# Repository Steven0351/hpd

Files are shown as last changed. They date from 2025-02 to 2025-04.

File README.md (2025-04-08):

## High Plains Drifter is a modular, curved mechanical keyboard that is ready to change the way you think about ergonomics in typing!  
*Innovative design that allows easy access to all keys, and specially designed modules that make the keyboard a unique tool, exclusively for your purpose*

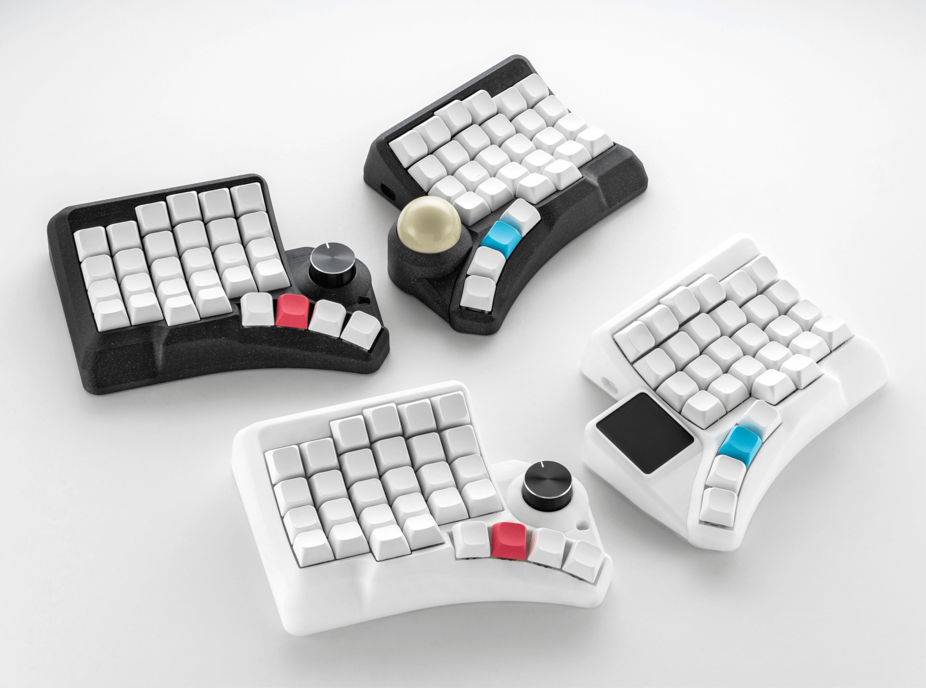
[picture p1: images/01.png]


## Design philosphy
This keyboard was designed with FDM printing in mind, the goal was to create a perfect curved case that can be easily printed and looks aesthetically pleasing with minimal amount of so called "steps" that plague similar 3D keyboards like Dactyl Manuform, it's design is similar to the [Velvet v3](https://github.com/ergohaven/velvet) keyboard but with 60% layout and addition of various interchangeable modules
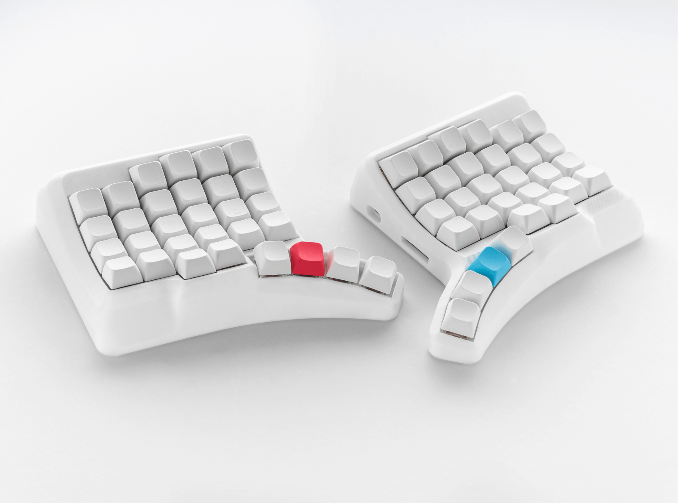
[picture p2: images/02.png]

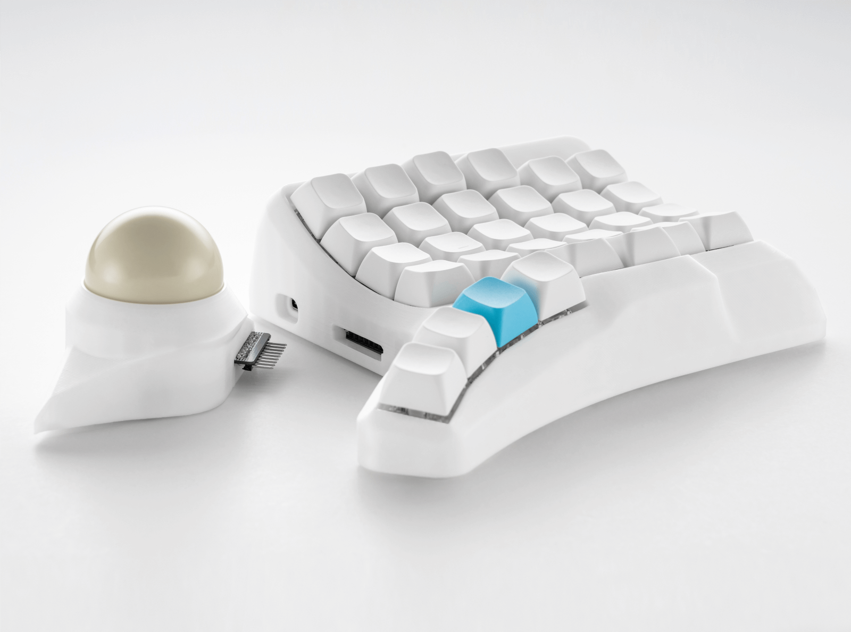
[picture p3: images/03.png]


## Features
- Modular, ergonomic 3D design
- 60 fully programmable keys, 15 additional layers for all your tasks
- Powered by RP2040 Zero and QMK firmware
- Hotswappable PCB (MX sockets) 
- Type-C output for connection between halves
- Easily remap any key and customize your keyboard with [Vial](https://get.vial.today/) 
- [Firmware](https://github.com/ergohaven/keymap_hub) is being constantly updated, get the latest QMK features for your keyboard from us ♥️  

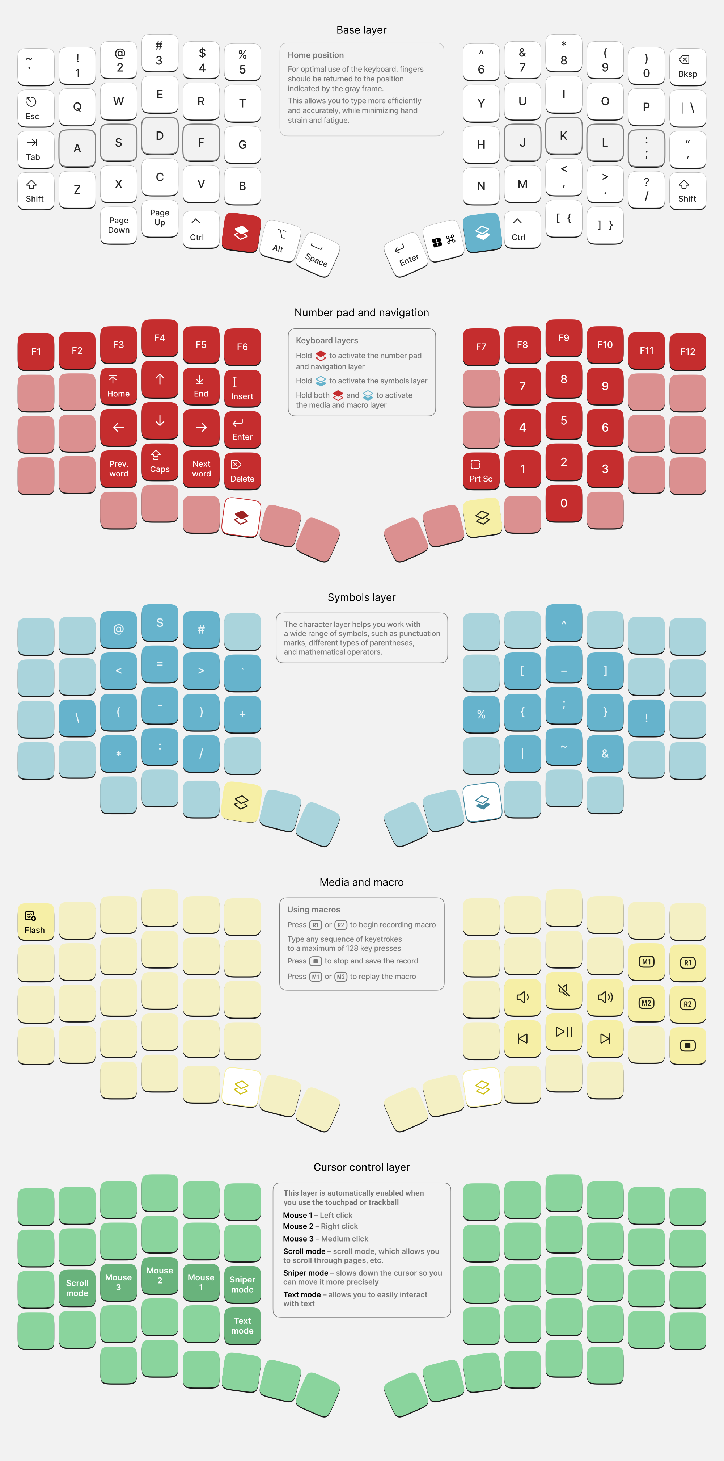
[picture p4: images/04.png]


## This repo contains all files related to this keyboard
PCB and schematic can be found [here](https://oshwlab.com/yuriiq/hpdv2)

### Build guide
- [English](https://github.com/ergohaven/hpd/blob/main/build_guide/build_guide_en.md)
- [Russian](https://github.com/ergohaven/hpd/blob/main/build_guide/build_guide_ru.md)

### BOM
#### Main case
- Switchplate + thumb keys + MCU holder PCBs
- 2   RP2040 Zero MCU
- 60 MX Hotswap sockets
- 60 1N4148W Diodes (SOD-123)
- 2   Male Pin Header Connector: 11 Pins, 2.54mm, 90 degree
- 2   Female Header Sockets: 11 Pins, 2.54mm, 90 degree
- 2   Female Header Sockets: 9 Pins, 2.54mm, 90 degree
- 4   Socket SH1.0 5 Pins, 1.00mm
- 2   Cable connector SH1.0 5 Pins, 1mm, 100mm, double head
- 2   1 - 100 kOhm resistors (0805)
- 2   USB Type-C daughterboard: 1.6mm thick
- 32 M2x4 Screws
- 10 M3x5 Inserts
- 10 M3x4 Screws
- 4 Magnets (5х10х2mm)
- 4 3M bumpons (8mm)

#### Encoder module
- Encoder PCB
- 1 Encoder EC11
- 1 Encoder cap
- 1 Male Pin Header Connector: 9 Pins, 2.54mm, 90 degree
- 1 1N4148W Diodes (SOD-123)
- 1 LED SK6812 mini-e
- 2 Magnets (5х10х2mm)
- 2 3M bumpons (8mm)

#### Touchpad module
- Touchpad PCB
- 1 Azoteq TPS43
- 1 Male Pin Header Connector: 9 Pins, 2.54mm, 90 degree
- 1 Connector PH2.0 4 pins, 2mm, 90 degree
- 1 Cable connector PH2.0 4 Pins, 2mm, 6mm, one head
- 2 Magnets (5х10х2mm)
- 1 plate 40x43x1 mm with rounding 3mm
- 1 PVC 40x43 mm sticker with rounding 3mm
- 2 3M bumpons (8mm)

#### Trackball module
- Trackball PCB
- 1 PWM3389 sensor
- 1 TPS73601DBVR
- 1 Male Pin Header Connector: 9 Pins, 2.54mm, 90 degree
- 1 Resistor 0805 10 kOm
- 1 Resistor 0805 39 Om
- 1 Resistor 0805 37.4 kOm
- 1 Resistor 0805 63.4 kOm
- 3 Capacitor 0805 100 nF
- 1 Capacitor 0805 1 uF
- 1 Capacitor 0805 4.7 uF
- 1 Capacitor 0805 10 uF
- 2 Magnets (5х10х2mm)
- 2 3M bumpons (8mm)
- 38mm billiard ball
- 3 bearings (6x2.5mm)
- 3 screws (M3x8)

## License 

The files in this repository are licensed under a Creative Commons Attribution-NonCommercial-ShareAlike 4.0 International License.

## Firmware
- [Pre-compiled files][1]
- [Source code][2]

[1]: https://github.com/ergohaven/keymap_hub
[2]: https://github.com/ergohaven/vial-qmk/tree/vial/keyboards/ergohaven

## Availability
The complete keyboard (not a diy kit!) is available for purchase at [ergohaven.xyz](https://ergohaven.xyz/shop)

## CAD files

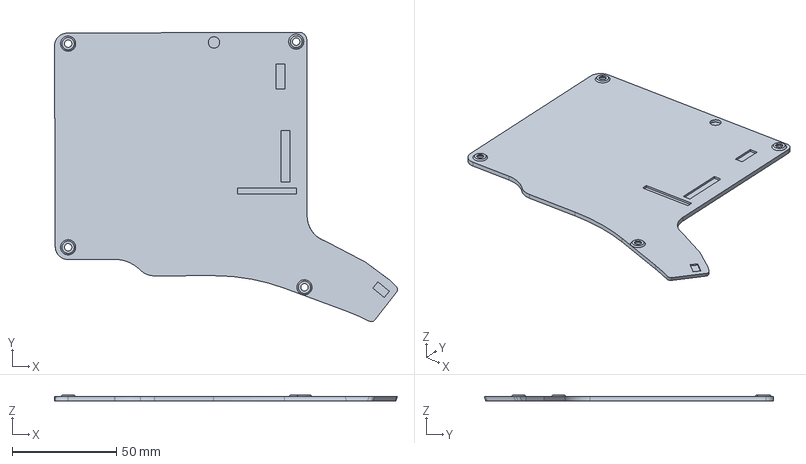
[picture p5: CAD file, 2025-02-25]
step/bot-left.stp
164.9 x 139.1 x 3.00 mm

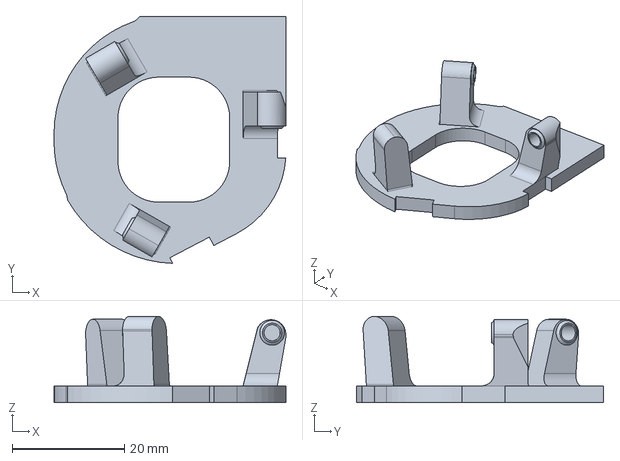
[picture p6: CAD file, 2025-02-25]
step/modules/trackball-holder.stp
41.3 x 43.9 x 15.4 mm

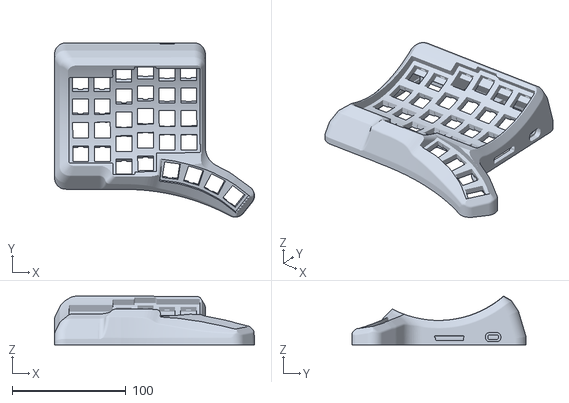
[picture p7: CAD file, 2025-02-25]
stl/body-left.stl
175.7 x 153.1 x 43.0

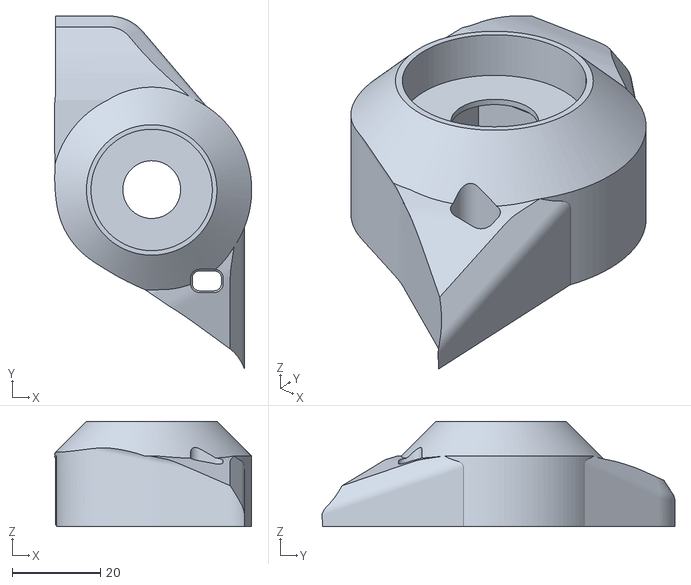
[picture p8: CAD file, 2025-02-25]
stl/modules/encoder-bl.stl
44.7 x 80.0 x 23.9

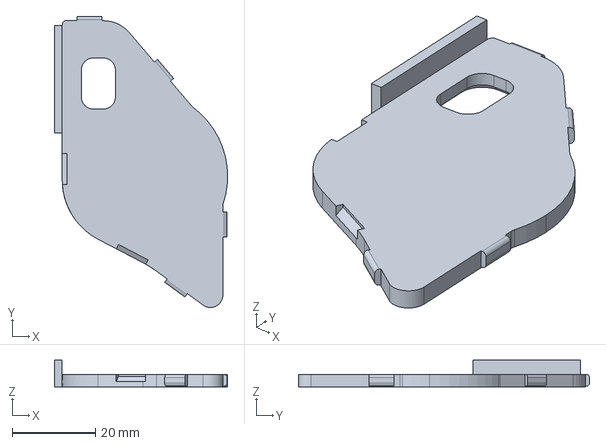
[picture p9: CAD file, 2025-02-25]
step/modules/encoder-bot.stp
41.7 x 70.0 x 6.48 mm

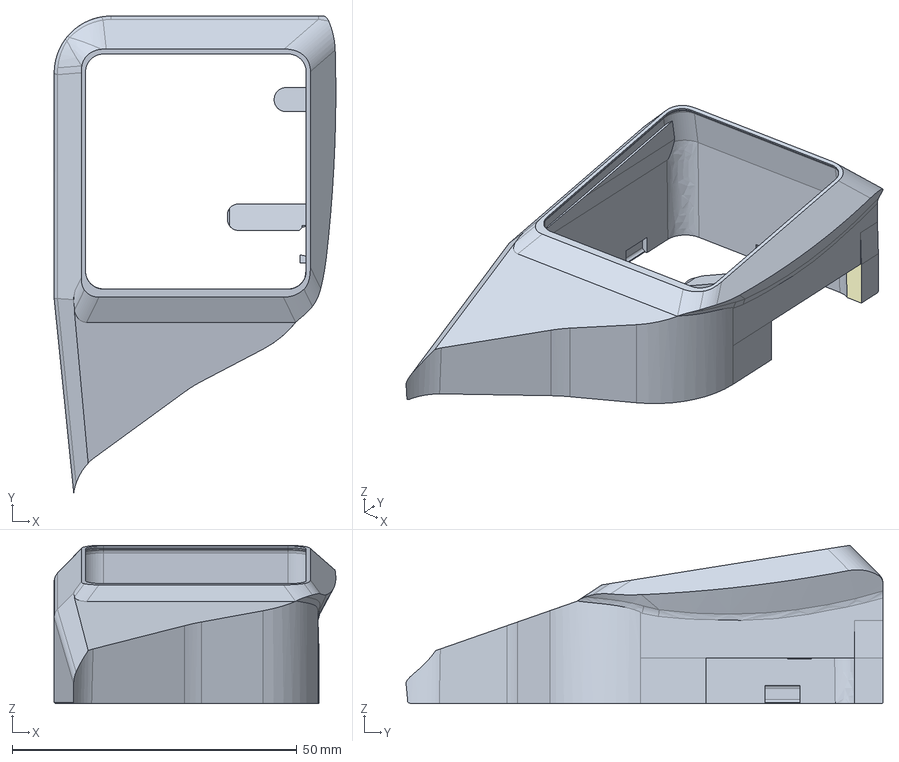
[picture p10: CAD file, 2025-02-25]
step/modules/touchpad-body.stp
49.5 x 83.8 x 27.9 mm

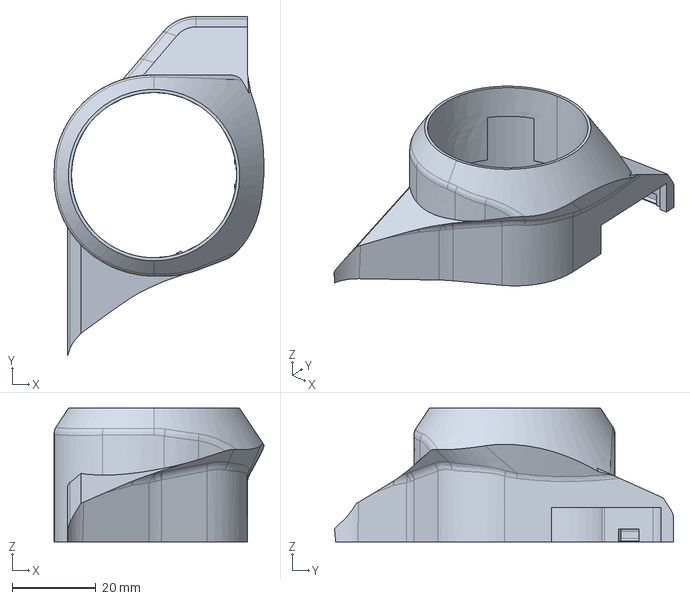
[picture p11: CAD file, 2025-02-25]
step/modules/trackball-body.stp
50.2 x 81.0 x 31.9 mm

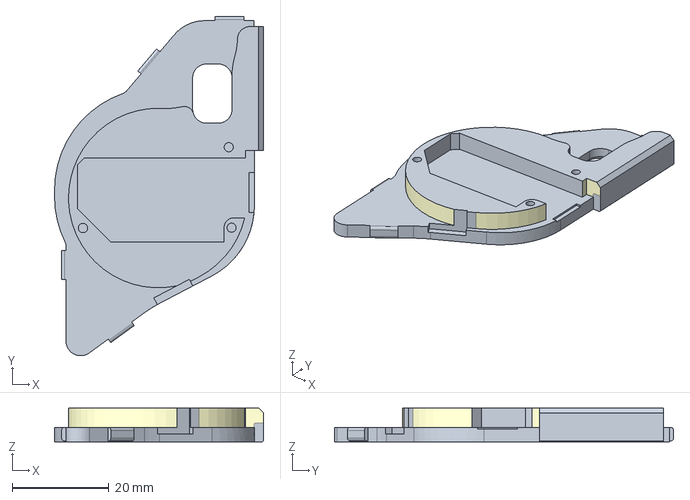
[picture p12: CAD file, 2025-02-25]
step/modules/trackball-bot.stp
43.3 x 70.3 x 6.98 mm

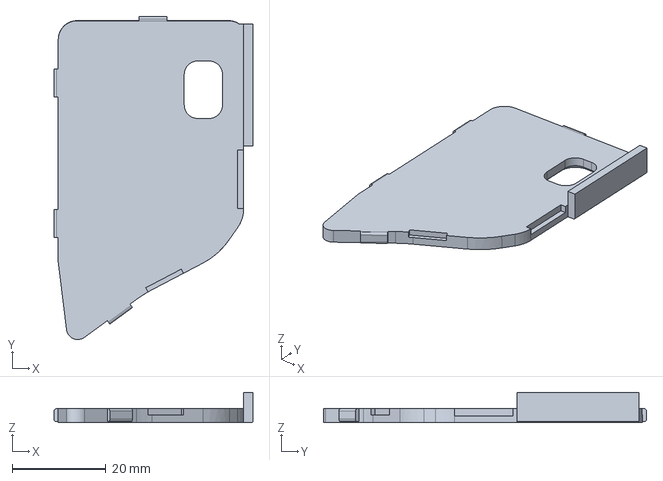
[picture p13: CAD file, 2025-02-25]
step/modules/touchpad-bot.stp
42.5 x 68.9 x 6.48 mm

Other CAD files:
step/bot-right.stp
stl/body-right.stl
stl/modules/encoder.stl
stl/modules/touchpad.stl
step/modules/encoder-body.stp
stl/bot-left.stl
stl/bot-right.stl
stl/modules/encoder-bot.stl
stl/modules/touchpad-bot.stl
stl/modules/trackball-body.stl
stl/modules/trackball-bot.stl
stl/modules/trackball-holder.stl

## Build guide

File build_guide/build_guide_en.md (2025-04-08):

# HPD v2 - how to assemble it yourself

## Components:

### Main keyboard case

-   1 pc. Switchplate PCB (FR4, 0.8mm thickness)
-   1 pc. Thumb cluster PCB (FR4, 0.8mm thickness)
-   1 pc. MCU holder PCB (FR4, 1mm thickness)
-   1 pc. 3D printed case (right and left halves)
-   2 pcs. RP2040 Zero MCU [(example)](https://aliexpress.ru/item/1005008447219836.html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)
-   60 pcs. MX Hotswap Sockets [(example)](https://aliexpress.ru/item/32965920593.html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)
-   60 pcs. 1N4148W Diodes (SOD-123) [(example)](https://aliexpress.ru/item/1005008585308341.html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)
-   2 pcs. PLS pin connectors, male: 11 Pins, 2.54mm, 90 degree [(example)](https://aliexpress.ru/item/1005003912826649.html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)
-   2 pcs. PBS sockets for connectors, female: 11 Pins, 2.54mm, 90 degree [(example)](https://aliexpress.ru/item/1005007724558861.html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)
-   2 pcs. PBS sockets for connectors, female: 9 Pins, 2.54mm, 90 degree [(example)](https://aliexpress.ru/item/1005007724558861.html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)
-   4 pcs. SH1.0 5 Pins, 1.00mm connectors [(example)](https://aliexpress.ru/item/1005005552109946.html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)
-   2 pcs. SH1.0 5 Pins, 1mm, 100mm, double head cable-connector [(example)](https://aliexpress.ru/item/4000820462275.html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)
-   2 pcs. 1-100kOhm resistors (0805) [(example)](https://aliexpress.ru/item/1005004542018347.html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)
-   4 pcs. Magnets n52 5x10x2 mm [(example)](https://aliexpress.ru/item/1005001564760861.html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)
-   2 pcs. USB Type-C mini-plate: 1.6mm thick [(example)](https://aliexpress.ru/item/1005005857575118.html)
-   32 pcs. M2x4 Screw [(example)](https://aliexpress.ru/item/1005005898007060.html)
-   10 pcs. M3x4 Brass Inserts [(example)](https://aliexpress.ru/item/1005004290019650.html)
-   10 pcs. M3x4 Screw [(example)](https://aliexpress.ru/item/1005005898007060.html)
-   1 pc. Type-C to Type-C cable (for connecting halves)
-   8 pcs. 3M bumpons/Silicone legs [(example)](https://aliexpress.ru/item/32912066603.html)
-   60 pcs. MX switches
-   60 pcs. Key caps

### Modules

#### Encoder 

-   1 pc. PCB (FR4, 1mm thickness)
-   1 pc. 3D printed case
-   1 pc. EC11 Encoder [(example)](https://aliexpress.ru/item/1005006781489585.html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)
-   1 pc. PLS pin connectors, male: 9 Pins, 2.54mm, 90 degree [(example)](https://aliexpress.ru/item/1005005614848270.html)
-   1 pc. 1N4148W Diode (SOD-123)
-   1 pc. LED sk6812 mini-e [(example)](https://aliexpress.ru/item/1005005237439694.html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)
-   2 pcs. Magnets n52 5x10x2 mm [(example)][(example)](https://aliexpress.ru/item/1005005614848270.html)
-   2 pcs. 3M bumpons/silicone legs [(example)](https://aliexpress.ru/item/32912066603.html)
-   1 pc. Knob for EC11 Encoder, Diameter 26mm, Height 17mm
-   2 pcs. LED insert (for Galaxy black case)

#### Touchpad 

-   1 pc. PCB (FR4, 1mm thickness)
-   1 pc. 3D printed case
-   1 pc. Azoteq TPS43 Touchpad
-   1 pc. PLS pin connectors, male: 9 Pins, 2.54mm, 90 degree [(example)](https://aliexpress.ru/item/1005005614848270.html)
-   1 pc. PH2.0 4 pins, 2mm, 90 degree connector [(example)](https://aliexpress.ru/item/1005008351868561.html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)
-   1 pc. PH2.0 4 Pins, 2mm, 6mm, one head cable-connector [(example)](https://aliexpress.ru/item/32936172012.html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)
-   2 pcs. Magnets n52 5x10x2 mm [(example)](https://aliexpress.ru/item/1005001564760861.html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)
-   2 pcs. 3M bumpons/Silicone legs [(example)](https://aliexpress.ru/item/32912066603.html)
-   1 pc. Touchpad surface 40x43x1 mm with 3mm rounded corners
-   1 pc. Touchpad protective film PVC 40x43 mm with 3mm rounded corners

#### Trackball 

-   1 pc. PCB (FR4, 1mm thickness)
-   1 pc. 3D printed case
-   1 pc. PMW3389DM sensor + lens
-   1 pc. TPS73601DBVR (Voltage Regulator)
-   1 pc. PLS pin connectors, male: 9 Pins, 2.54mm, 90 degree [(example)](https://aliexpress.ru/item/1005005614848270.html)
-   1 pc. Resistor 0805 10 kOhm [(example)](https://aliexpress.ru/item/1005004542018347.html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)
-   1 pc. Resistor 0805 39 Ohm [(example)](https://aliexpress.ru/item/1005004542018347.html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)
-   1 pc. Resistor 0805 37.4 kOhm [(example)](https://aliexpress.ru/item/1005008488375993.html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)
-   1 pc. Resistor 0805 63.4 kOhm [(example)](https://aliexpress.ru/item/1005007715575103.html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)
-   3 pcs. Capacitor 0805 100 nF [(example)](https://aliexpress.ru/item/1005007108081207.html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)
-   1 pc. Capacitor 0805 1 uF [(example)](https://aliexpress.ru/item/1005007108081207.html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)
-   1 pc. Capacitor 0805 4.7 uF [(example)](https://aliexpress.ru/item/1005007108081207.html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)
-   1 pc. Capacitor 0805 10 uF [(example)](https://aliexpress.ru/item/1005007108081207.html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)
-   2 pcs. Magnets n52 5x10x2 mm [(example)](https://aliexpress.ru/item/1005001564760861.html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)
-   2 pcs. 3M bumpons/Silicone legs [(example)](https://aliexpress.ru/item/32912066603.html)
-   1 pc. Ball 38 mm
-   3 pcs. Bearing balls steel/ceramic diameter 3mm

## Tools:

-   Soldering iron
-   Solder (flux-containing)
-   Nippers
-   Tweezers
-   Screwdriver for M3 and M2 screws
-   Pliers

## Assembly sequence

### Preparation of MCU Holders

1.  Installation of resistors
2.  Installation of the microcontroller
3.  Installation of Type-C connectors
4.  Installation of SH1.0 5 Pins, 1.00mm connectors
5.  Installation of PBS 11-Pin and 9-Pin sockets
6.  Microcontroller firmware

### Preparing the switchplate

1.  Applying solder to the pads
2.  Installation of hotswap sockets and diodes

### Preparing the thumb cluster PCB

1.  Installation of SH1.0 5 Pins, 1.00mm connectors
2.  Applying solder and installation of hotswap sockets and diodes

### Preparing the trackball module PCB

1.  Installation of the TPS73601DBVR IC
2.  Applying solder to the pads
3.  Installation of resistors and capacitors
4.  Installation of the PMW3389DM sensor
5.  Installation of PLS pin connectors
6.  Installation of the lens

### Preparing the encoder module PCB

1.  Installation of 1N4148W diodes (SOD-123)
2.  Installation of sk6812 mini-e LEDs
3.  Installation of PLS pin connectors
4.  Installation of the encoder

### Preparing the touchpad module PCB

1.  Installation of PLS pin connectors
2.  Installation of the PH2.0 4 pins, 2mm connector

### Main case assembly

1.  Installation of switches (initial set for alignment)
2.  Installation of the Thumb cluster PCB
3.  Installation of the Switchplate
4.  Installation of magnets into the case
5.  Installation of brass inserts
6.  Installation of the MCU holder
7.  Connecting the cable-connectors
8.  Installation of remaining switches and keyboard check
9.  Installation of the bottom plate and keycaps

### Encoder module assembly

1.  Installation of LED insert (Galaxy black case)
2.  Installation of magnets
3.  Installation of the PCB
4.  Installation of the cover, knob, and bumpons

### Trackball module assembly

1.  Installation of bearing balls
2.  Installation of magnets
3.  Installation of the PCB
4.  Installation of the cover and bumpons

### Touchpad module assembly

1.  Installation of the cable-connector
2.  Installation of the touchpad surface
3.  Installation of the touchpad into the case
4.  Installation of the PCB
5.  Installation of magnets
6.  Installation of the cover and bumpons

### Preparation of MCU holders

#### Installing resistors

First, you need to prepare the MCU Holder PCB. Install resistors on both holder halves. On the right half - onto the R3 pad, on the left - onto R2.
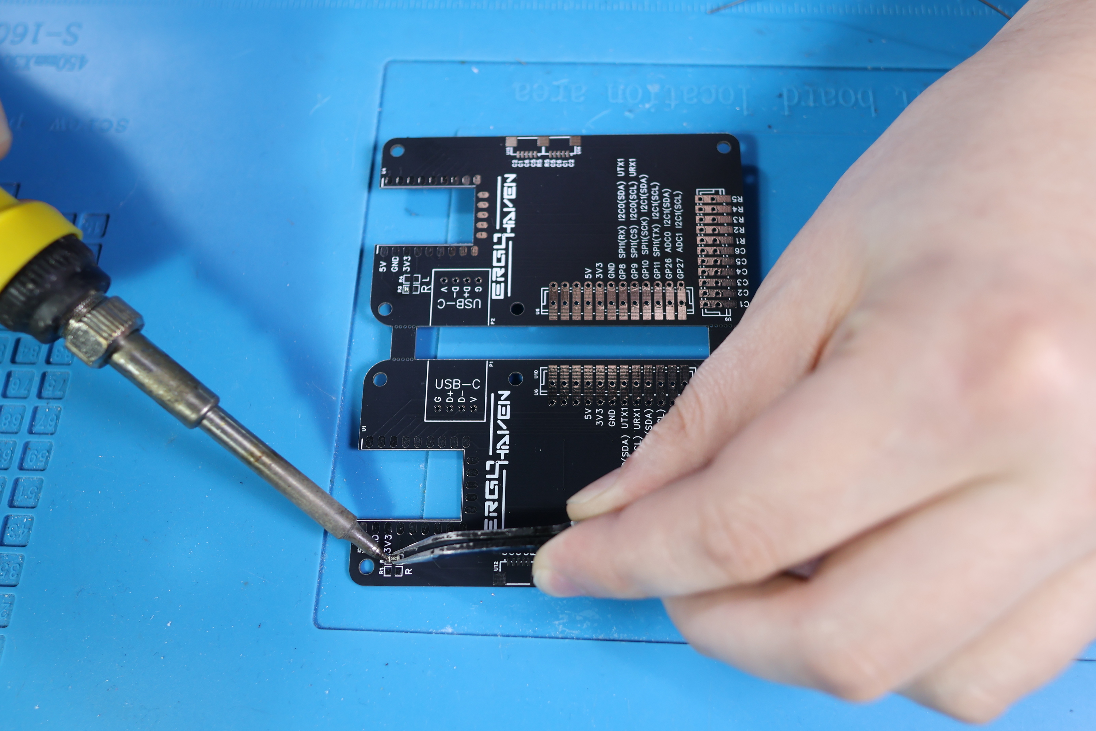
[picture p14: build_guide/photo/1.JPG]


#### Installing the microcontroller

Do not mix up the installation side. Place the microcontroller level and first solder pins 0 and 13 to fix it on the board. After ensuring the microcontroller is aligned correctly, solder the remaining contacts.
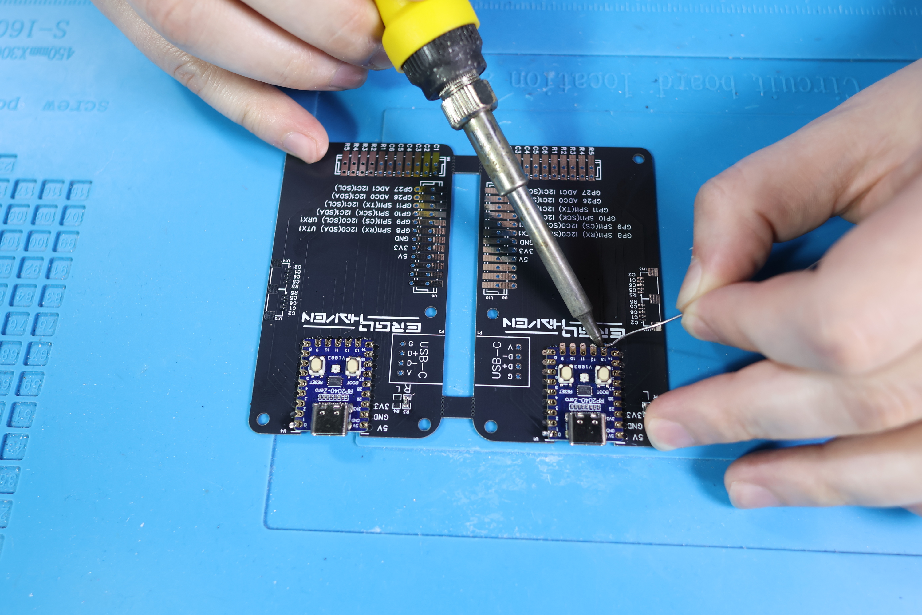
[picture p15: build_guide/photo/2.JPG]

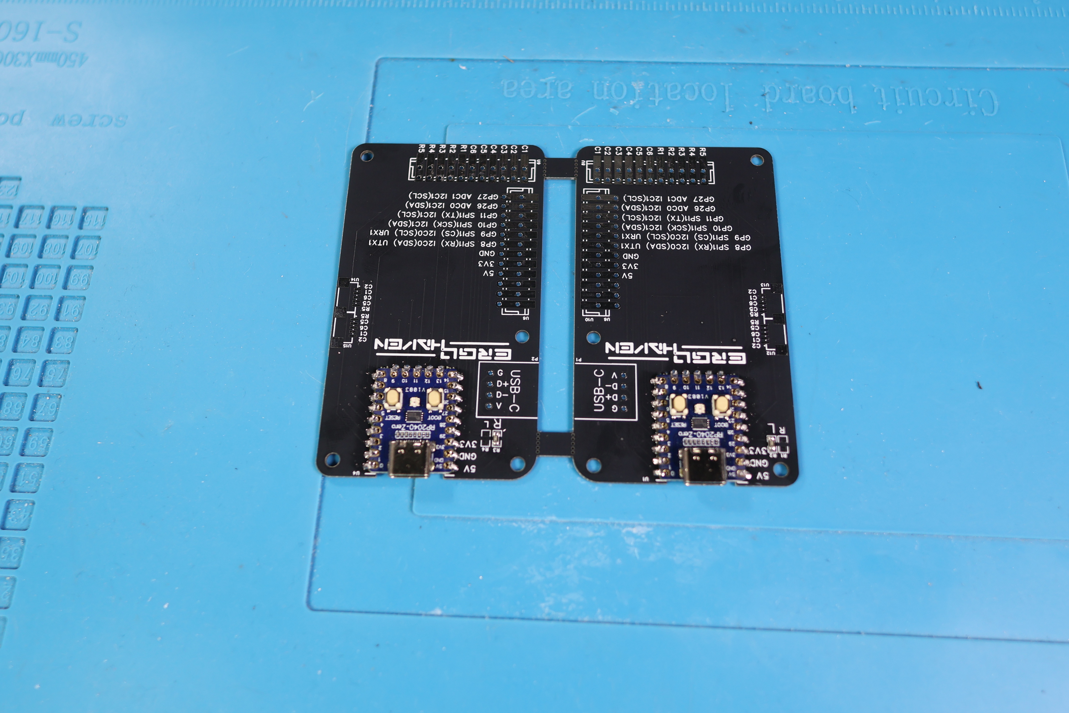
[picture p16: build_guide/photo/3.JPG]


#### Installing Type-C connectors

Place the Type-C mini-plate onto the holder PCB. Solder one pin of the PLS connector (which goes through the Type-C mini-plate and holder PCB) on the back side to temporarily fix it, as shown in Fig. 1.
Then, on the other side (top side), solder one pin of the Type-C connector itself to fix its position relative to the PLS connector, as shown in Fig. 2. Next, solder all pins of the PLS connector on the top side, as shown in Fig. 3.
Afterward, trim the excess legs of the PLS connector on the back side using nippers (Fig. 4) and solder the remaining pins of the Type-C connector on the back side (Fig. 5).

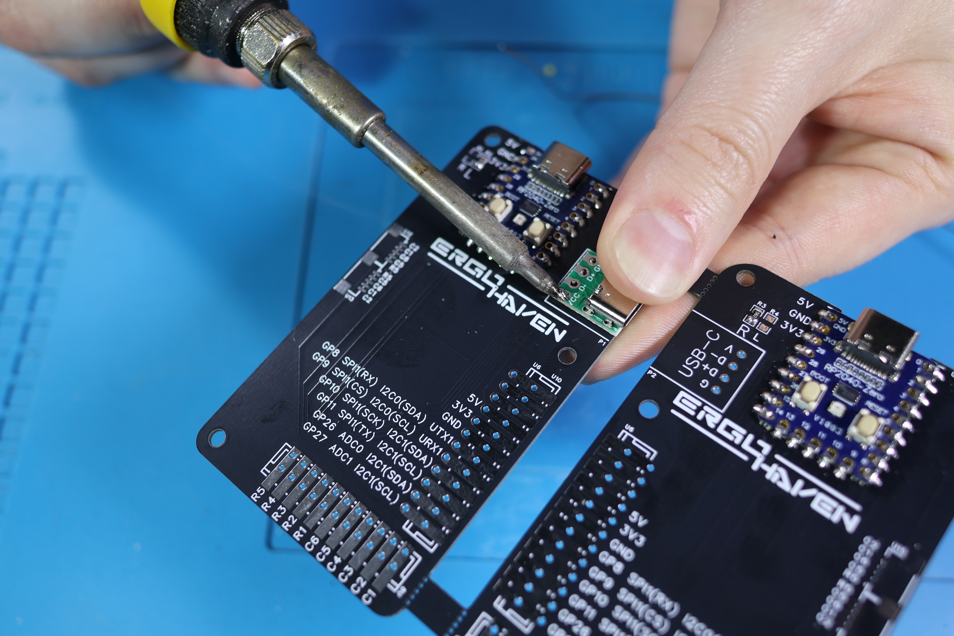
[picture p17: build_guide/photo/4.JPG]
 
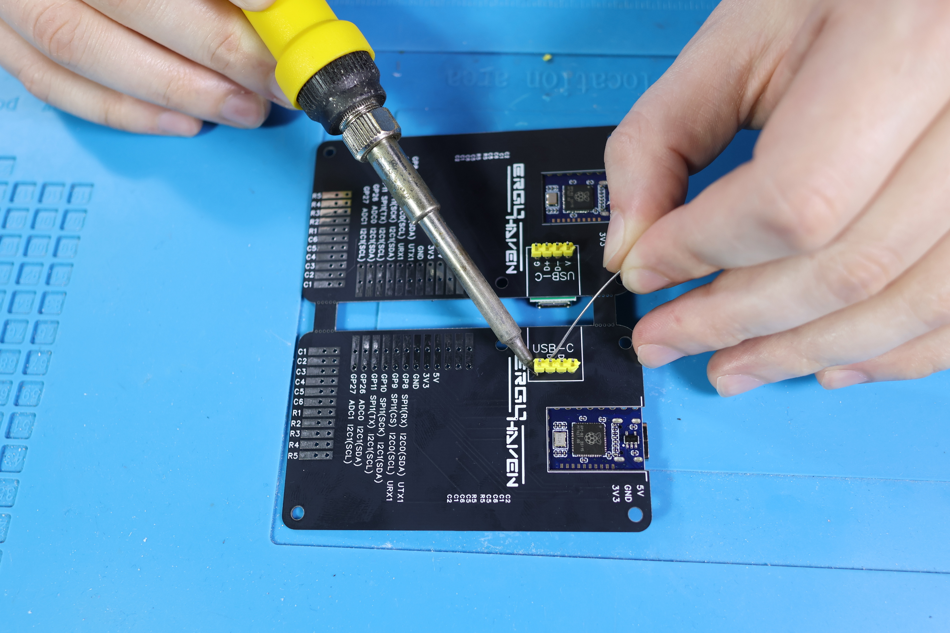
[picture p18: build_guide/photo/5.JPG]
 
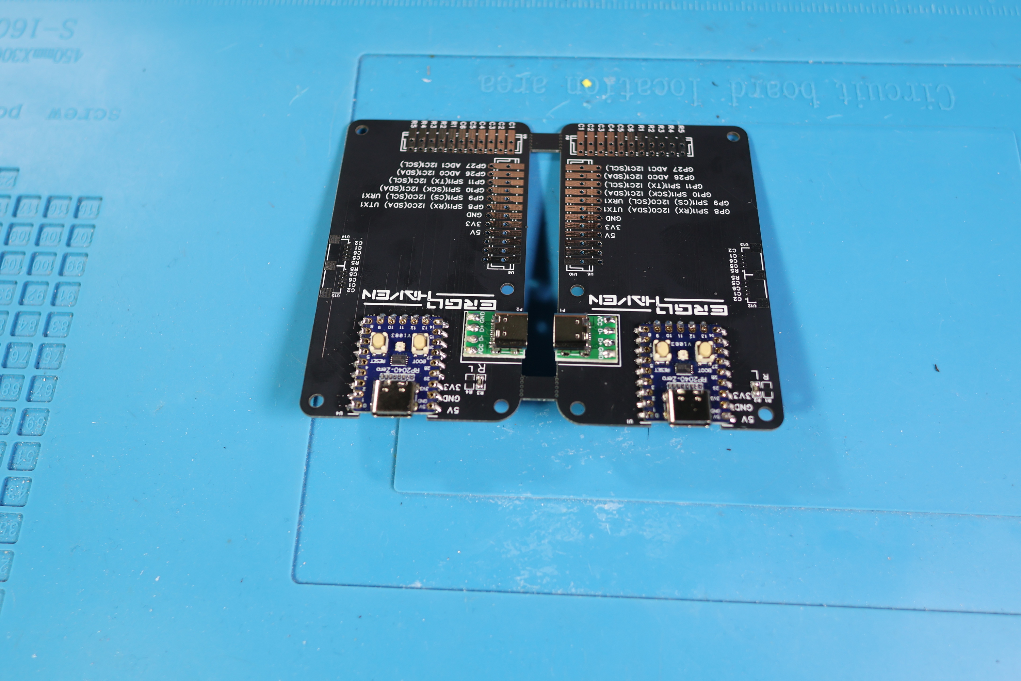
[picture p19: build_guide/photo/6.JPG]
 
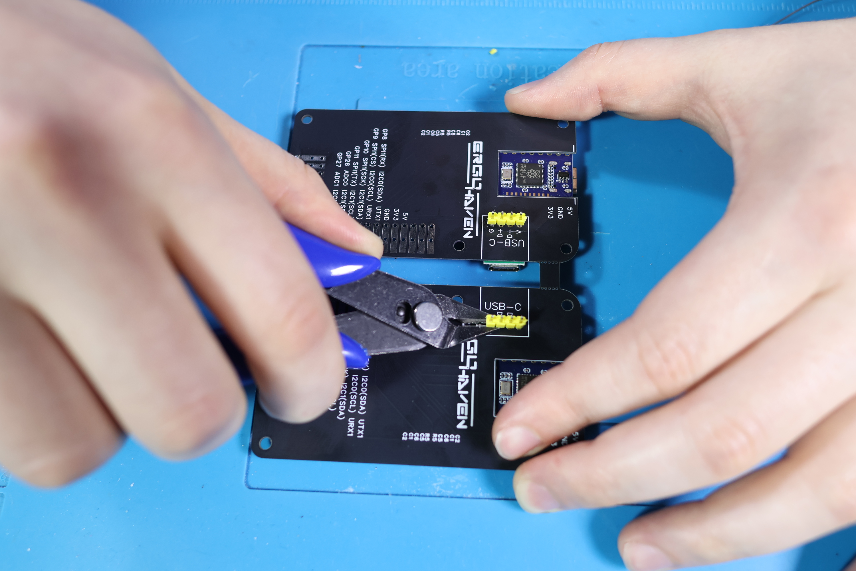
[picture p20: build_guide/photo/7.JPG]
 
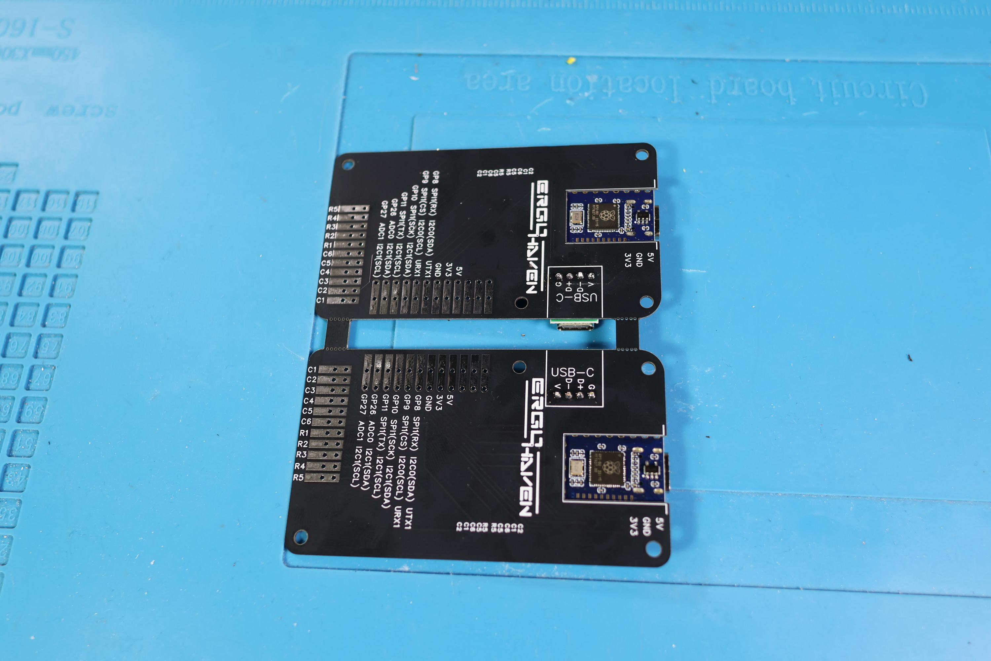
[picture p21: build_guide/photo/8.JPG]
 

#### Installing SH1.0 5 Pins, 1.00mm connectors

Apply solder to one of the large side pads to fix the connector's position
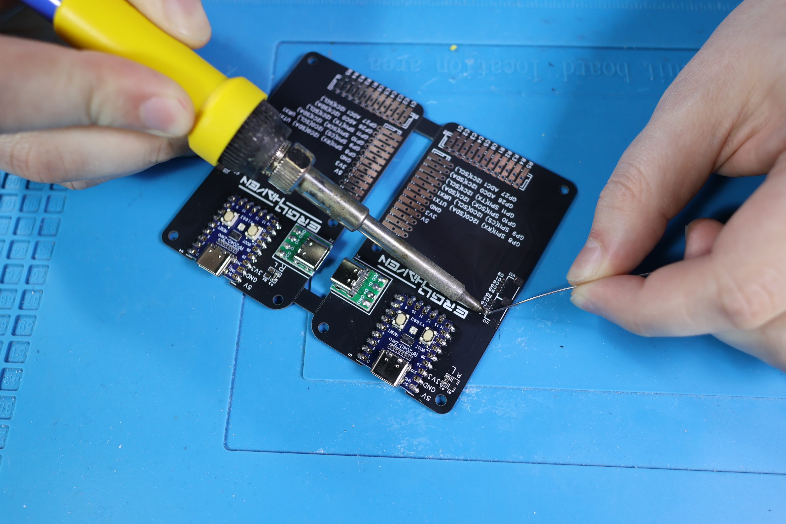
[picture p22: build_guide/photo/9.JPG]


Place the connector and solder the remaining pins. Ensure the side mounting tabs are securely soldered for mechanical strength.
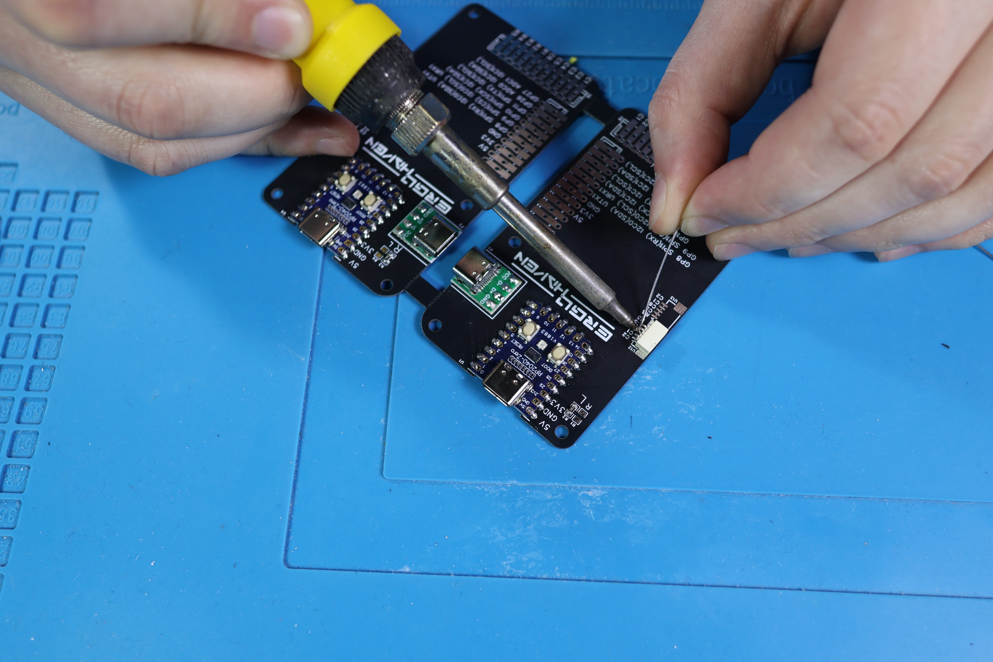
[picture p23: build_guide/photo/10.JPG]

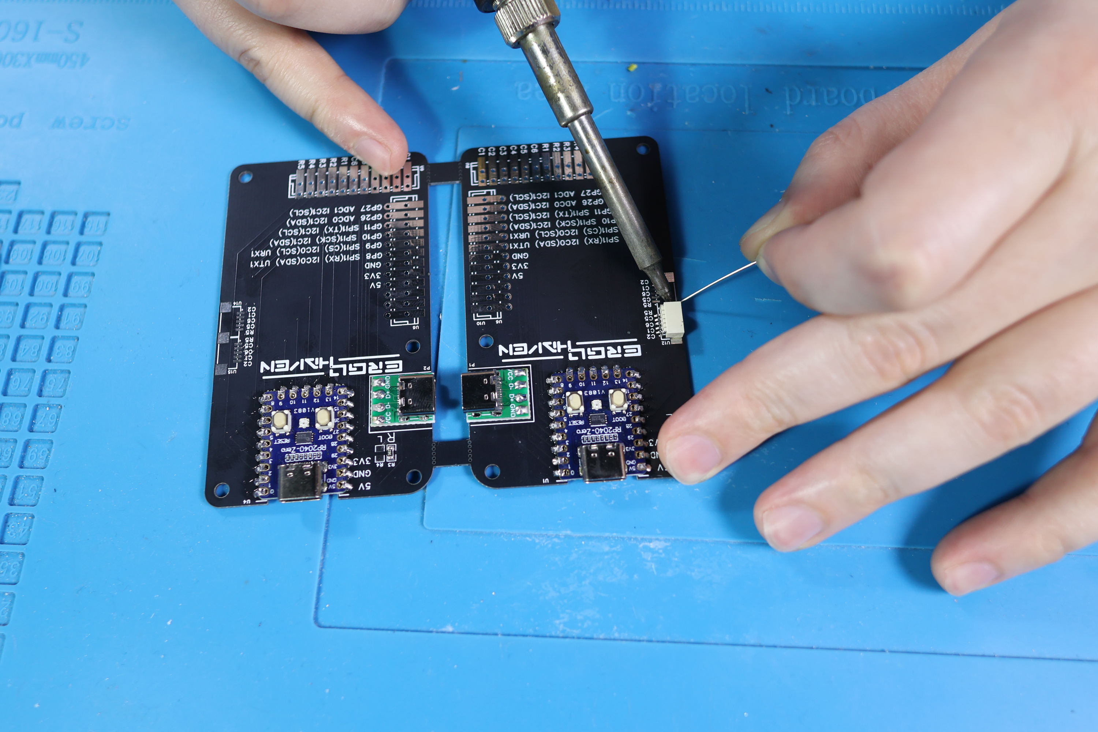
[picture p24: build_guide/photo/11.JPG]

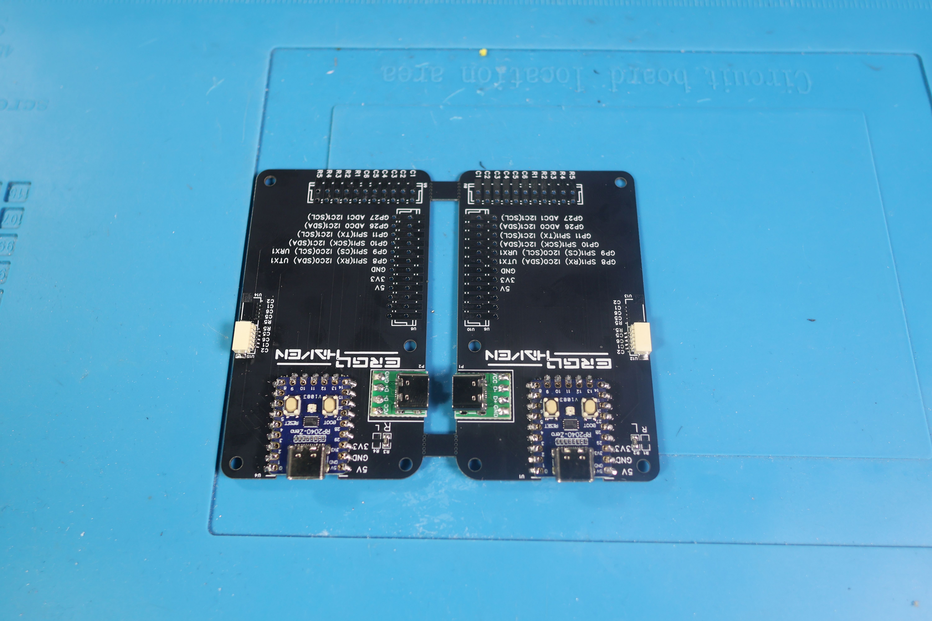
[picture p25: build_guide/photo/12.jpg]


#### Installing PBS 11-Pin and 9-Pin sockets

Solder one end pin of the PBS 11-Pin socket first to fix its position. Then solder the remaining pins.
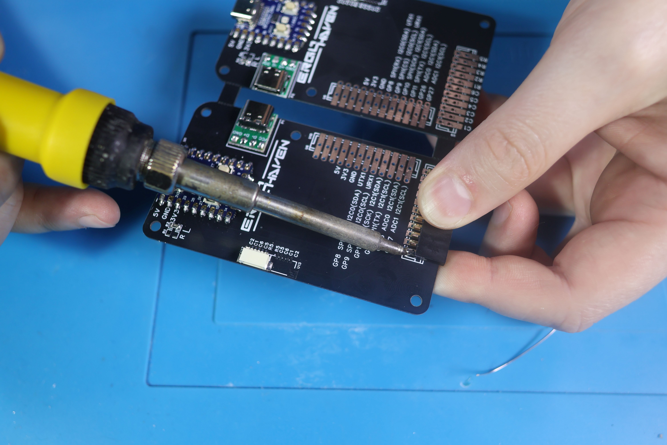
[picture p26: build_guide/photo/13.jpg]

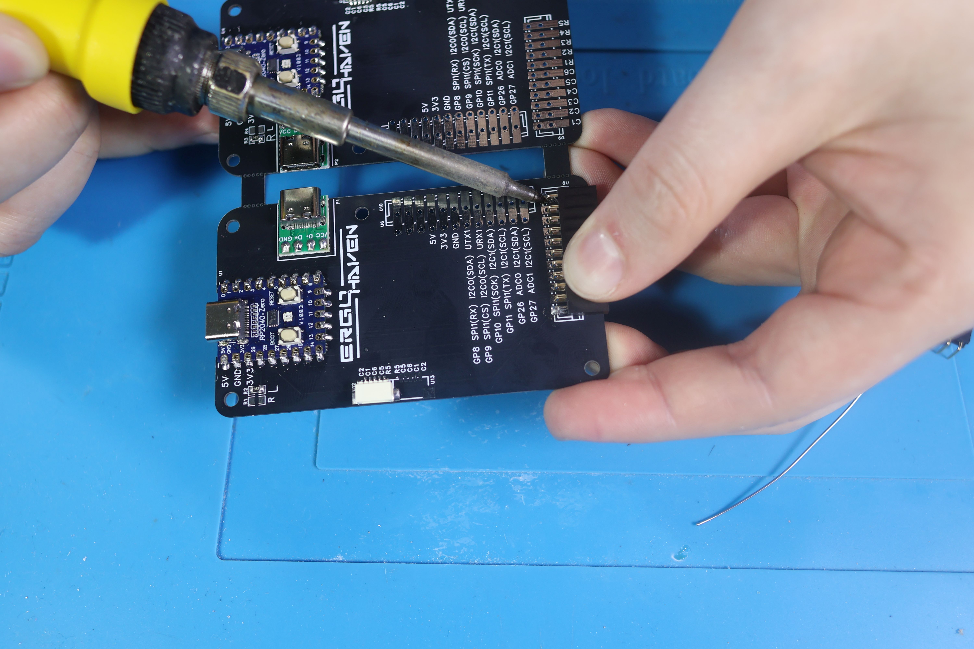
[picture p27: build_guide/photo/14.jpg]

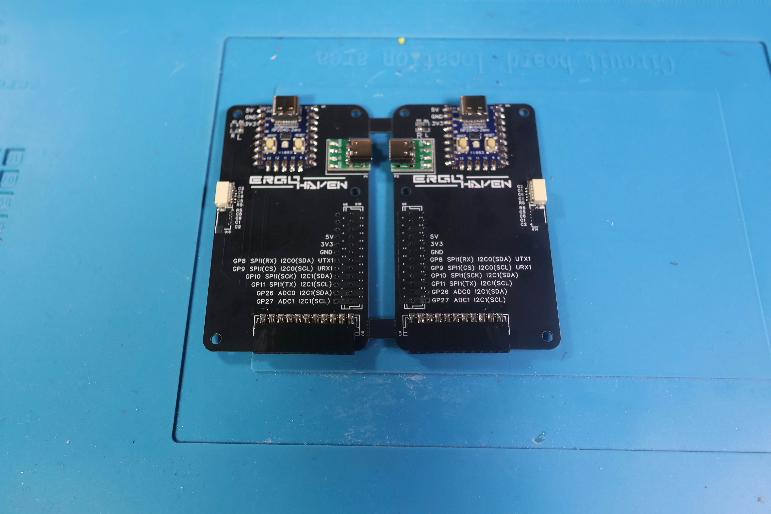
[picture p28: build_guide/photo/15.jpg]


Then, solder the PBS 9-Pin sockets, positioning them as shown in the picture.
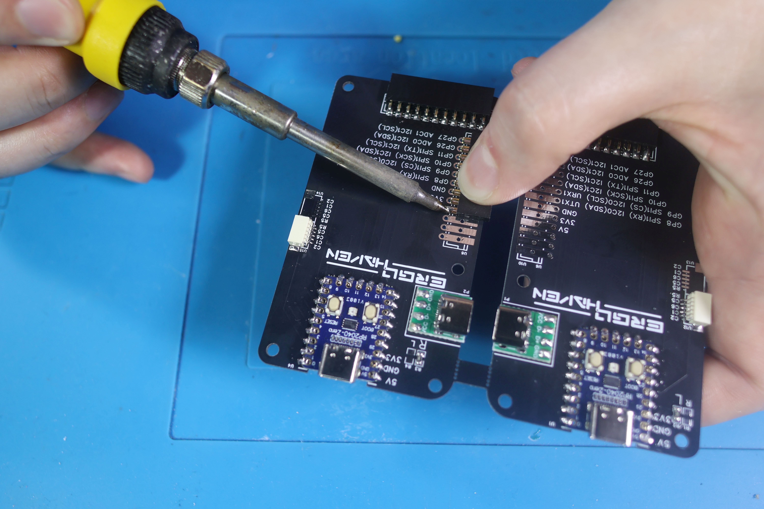
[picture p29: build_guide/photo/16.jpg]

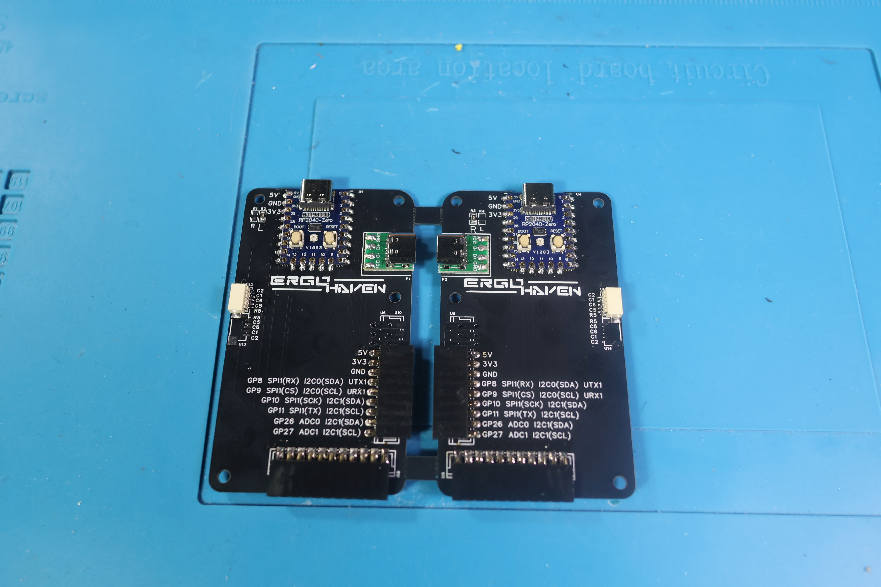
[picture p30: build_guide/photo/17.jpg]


Afterward, trim the pins on the reverse side using nippers.
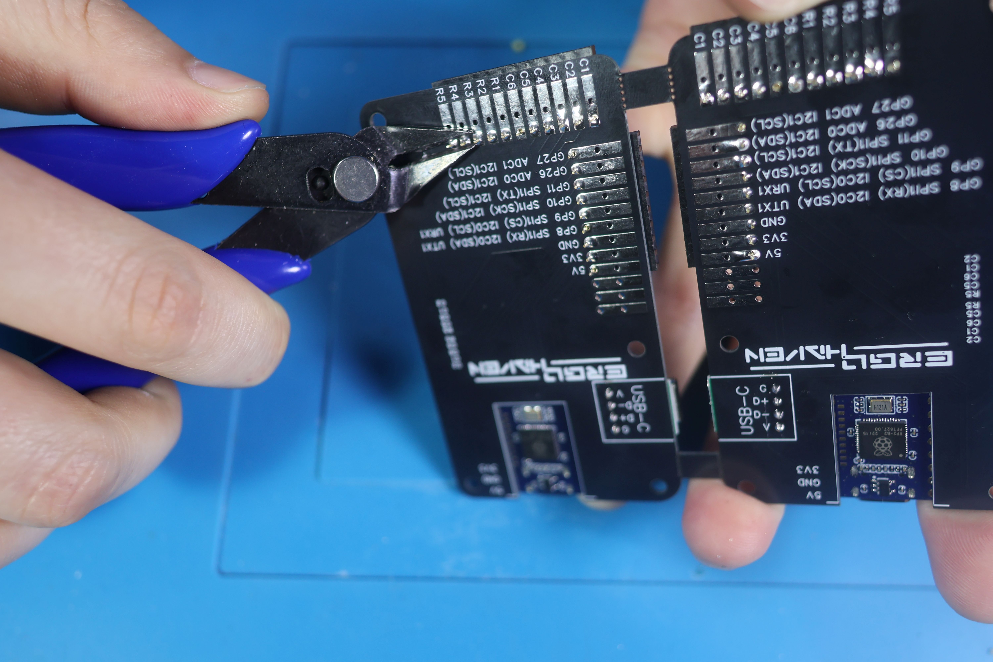
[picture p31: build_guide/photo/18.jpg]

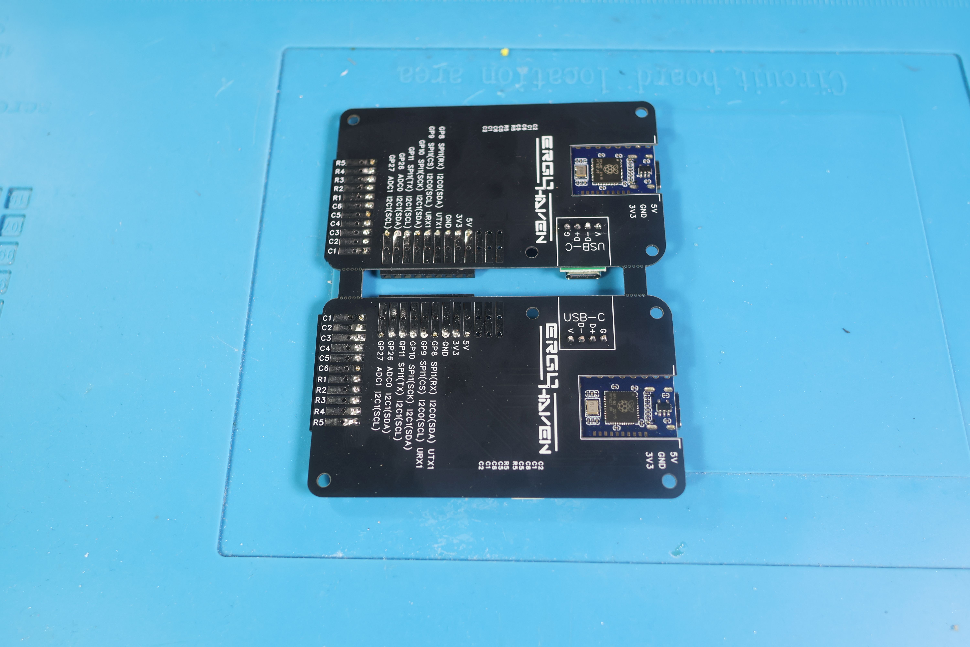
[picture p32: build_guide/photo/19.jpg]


#### Microcontroller firmware

After finishing soldering the holders, you need to flash them:
-   Connect the microcontroller to the PC.
-   The microcontroller should be identified as a USB drive.
-   Drag and drop the [firmware file](https://github.com/ergohaven/keymap_hub/) onto it.
-   The microcontroller is flashed.

If your RP2040-Zero is not detected as a drive:
Hold down the 'Boot' button on the microcontroller while connecting the USB cable. Then repeat the step of dragging the `.uf2` firmware file.

### Preparing the switchplate

#### Applying solder to contact pads

First, prepare the PCB. Apply a small amount of solder to one pad for each component location (diodes and sockets). This makes soldering the components easier.
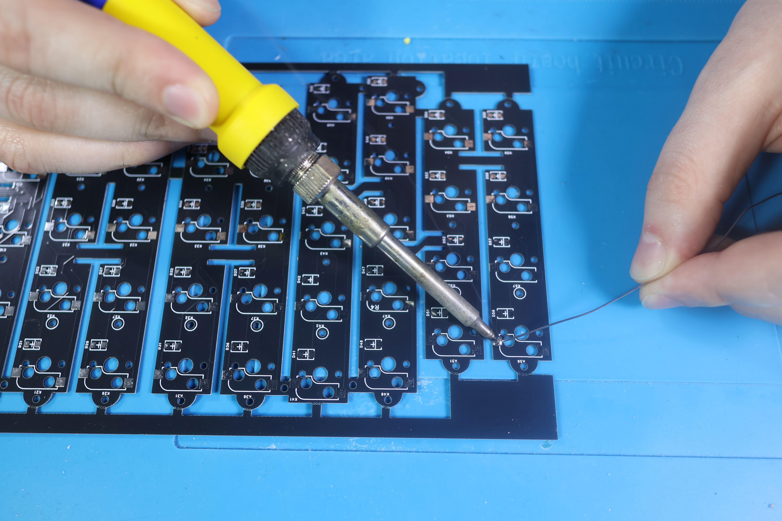
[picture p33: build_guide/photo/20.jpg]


#### Installing hotswap sockets and diodes

Diodes have polarity; install them correctly. The cathode is marked with a white line on the diode. The PCB also has a silkscreen marking with a similar line. Solder "line to line".
All diodes must be installed in the same direction. Solder the diode first to the pre-tinned pad, then solder the other pad.

Next, install the hotswap sockets and solder them. Solder one pin first, check alignment, then solder the second pin.
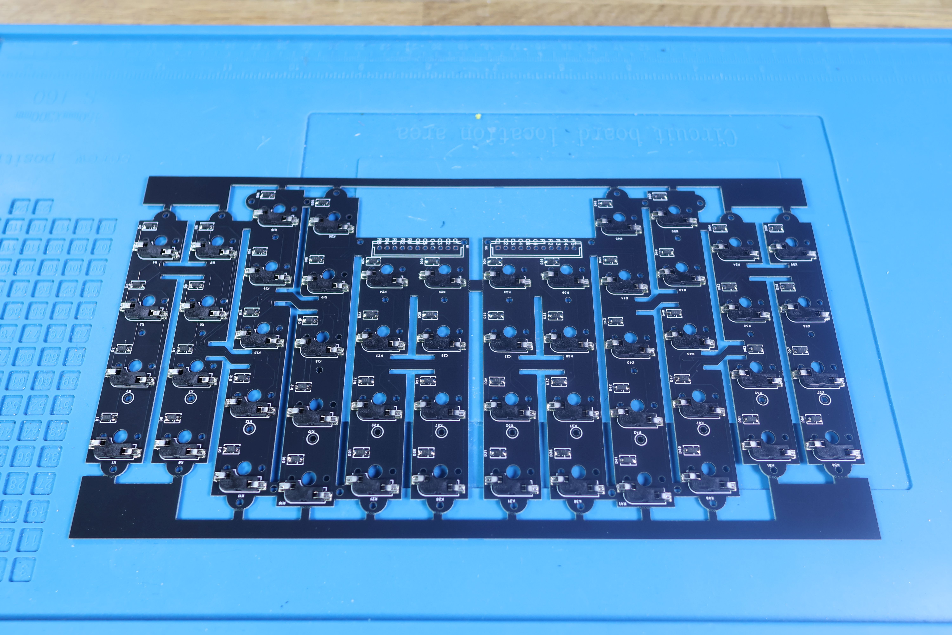
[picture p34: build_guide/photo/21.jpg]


### Preparing the thumb cluster PCB

#### Installing SH1.0 5 Pins, 1.00mm connectors

Solder the connector similarly to how it was done on the holder PCB. Pay attention that the side mounting tabs are securely soldered.
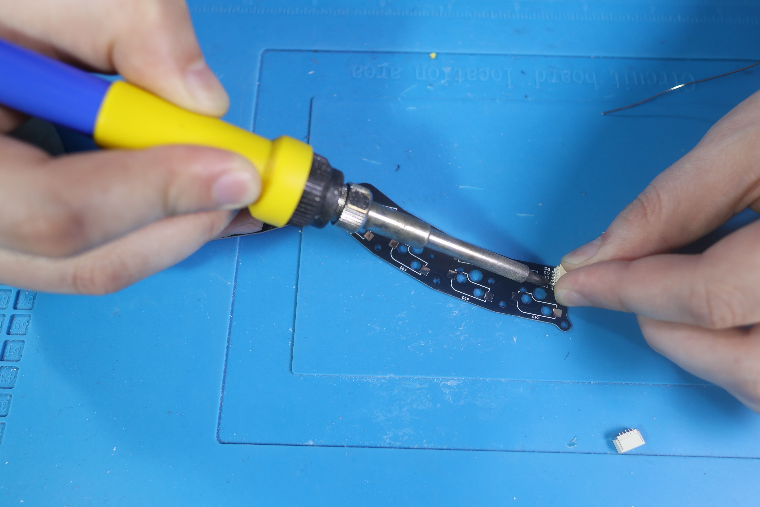
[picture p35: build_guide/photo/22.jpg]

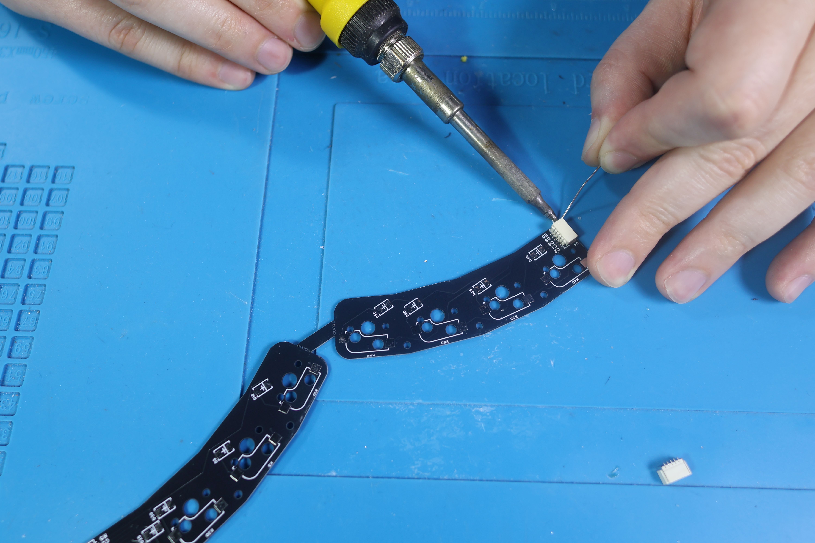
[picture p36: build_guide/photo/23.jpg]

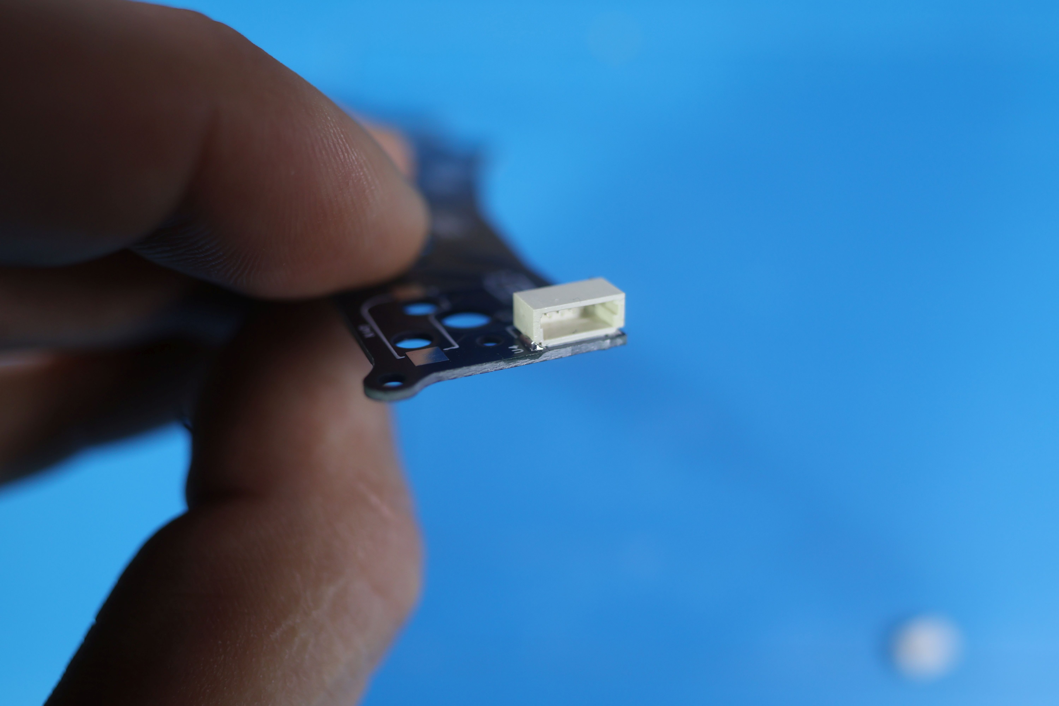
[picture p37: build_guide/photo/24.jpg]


#### Applying solder and installing components

Apply solder to one pad for each diode and socket location. Install and solder the diodes (observing polarity) and hotswap sockets, just like on the main switchplate.
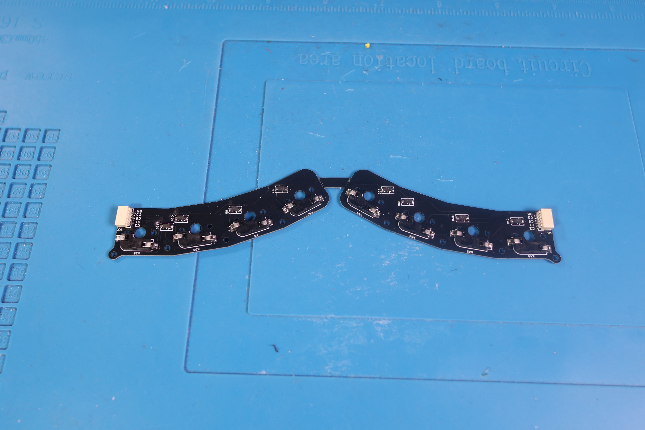
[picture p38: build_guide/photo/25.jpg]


### Preparing the trackball module PCB

#### Installation of the TPS73601DBVR IC

Apply solder to the large central pad (thermal pad) to help fix the IC's position.
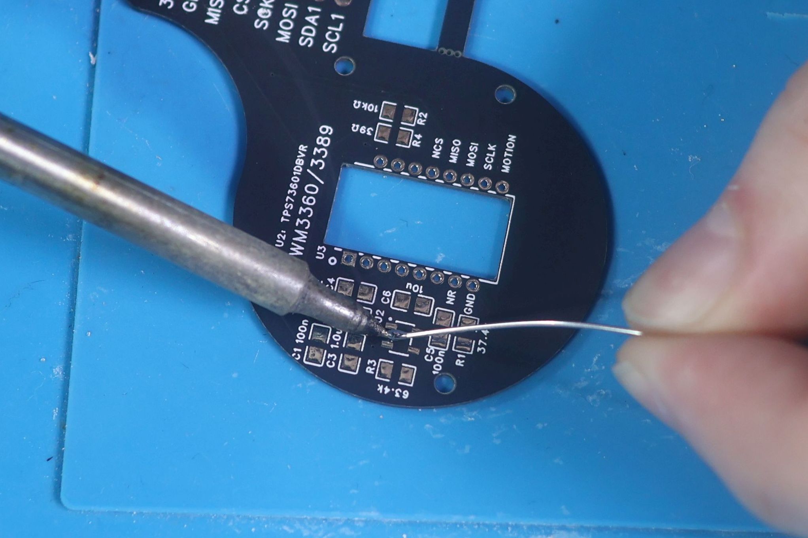
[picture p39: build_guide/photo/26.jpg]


Next, position the IC correctly (check pin 1 indicator) and solder it.
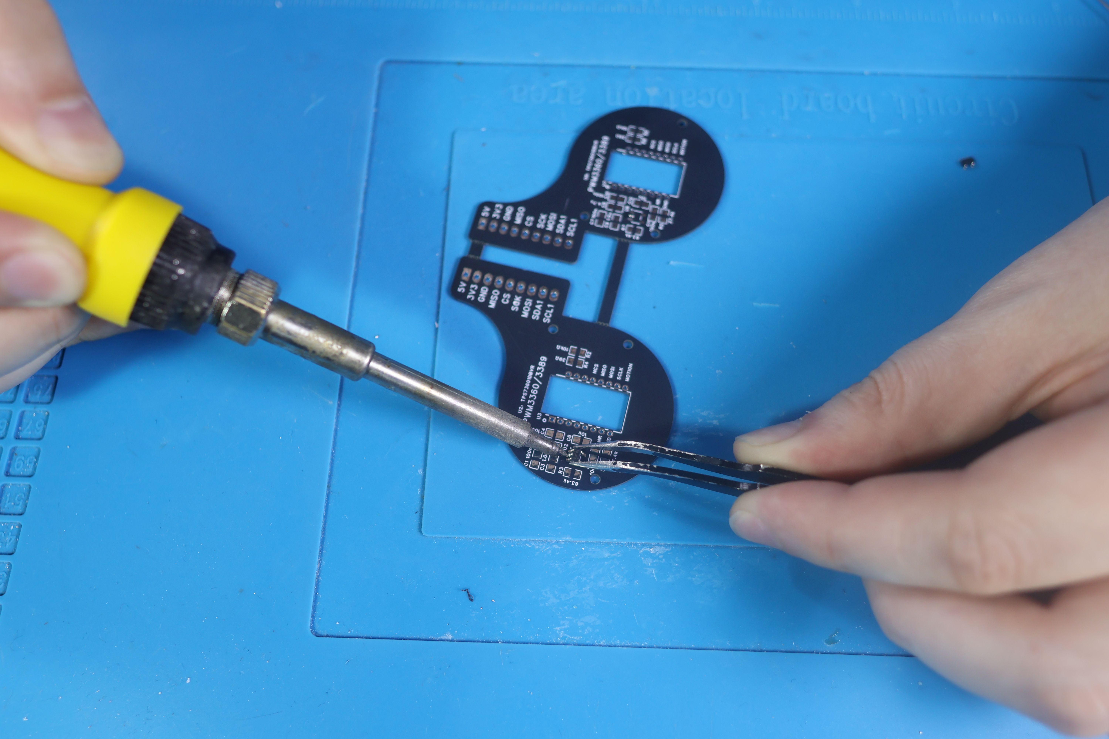
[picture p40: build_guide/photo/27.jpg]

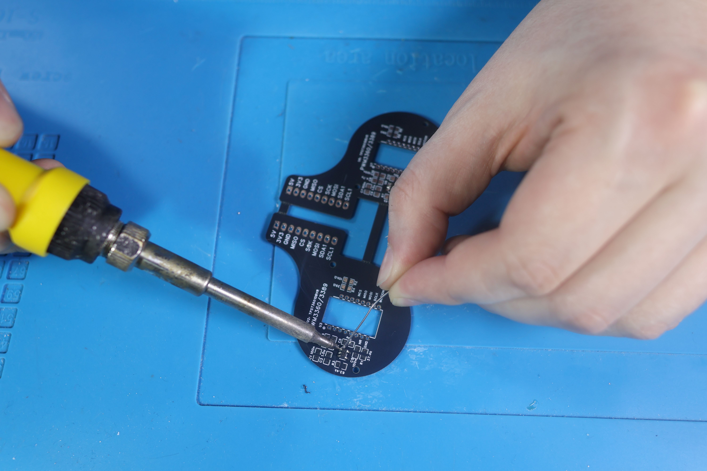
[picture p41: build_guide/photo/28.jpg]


#### Applying solder to contact pads

Apply solder to one pad for each resistor and capacitor location.
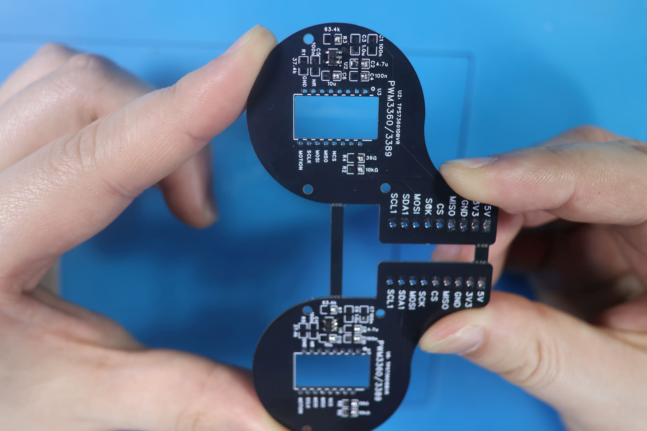
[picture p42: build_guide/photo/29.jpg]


#### Installation of resistors and capacitors

Solder all resistors and capacitors according to the silkscreen markings. These components do not have polarity.
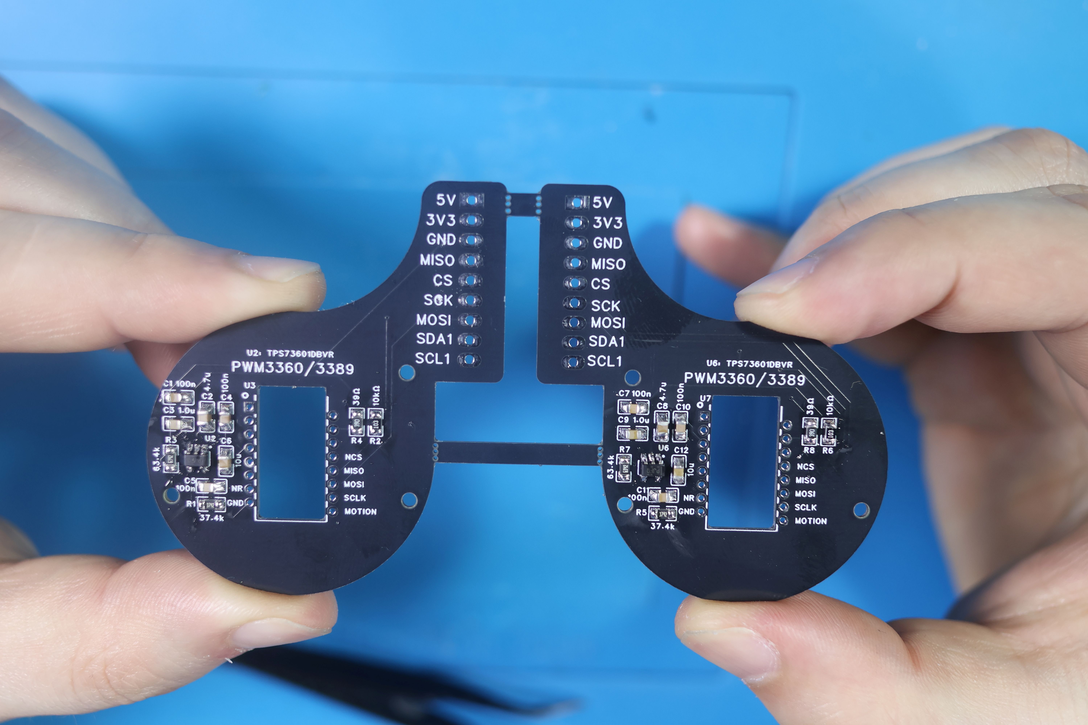
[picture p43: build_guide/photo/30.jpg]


#### Installation of the PMW3389DM sensor

Position the sensor aligning the mark/notch on the sensor with the mark on the PCB ("mark to mark") as shown, and solder its pins.
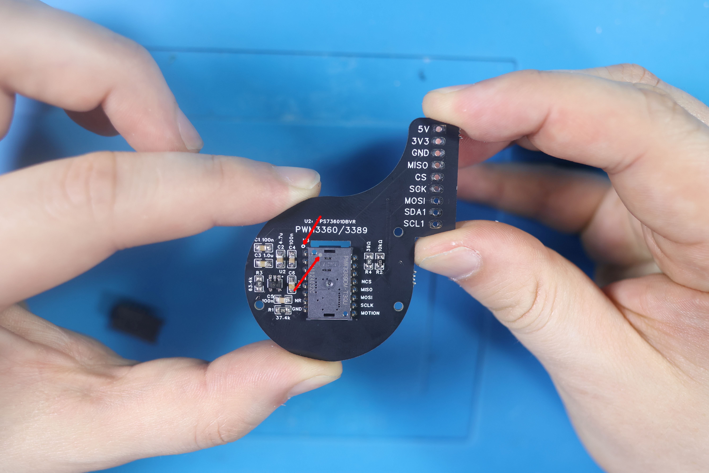
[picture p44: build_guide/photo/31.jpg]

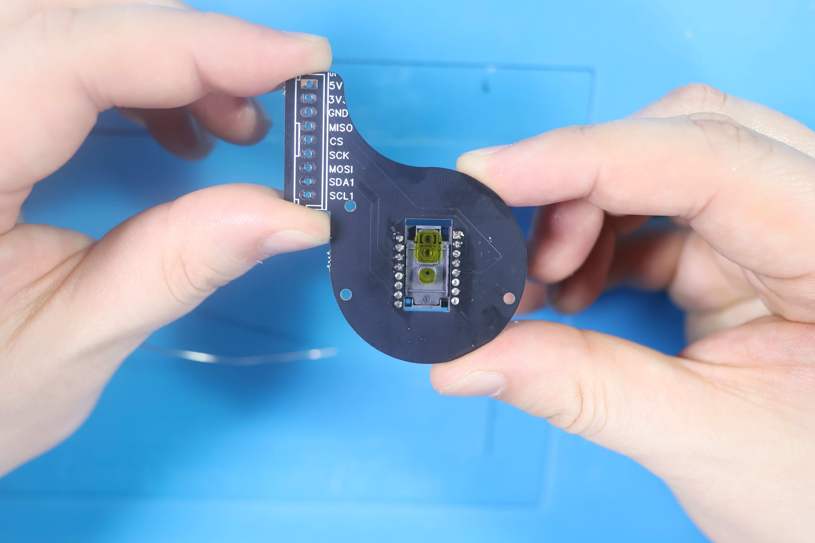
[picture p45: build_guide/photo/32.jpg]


#### Installation of PLS pin connectors

Solder one end pin first to fix the position. Then solder the remaining pins.
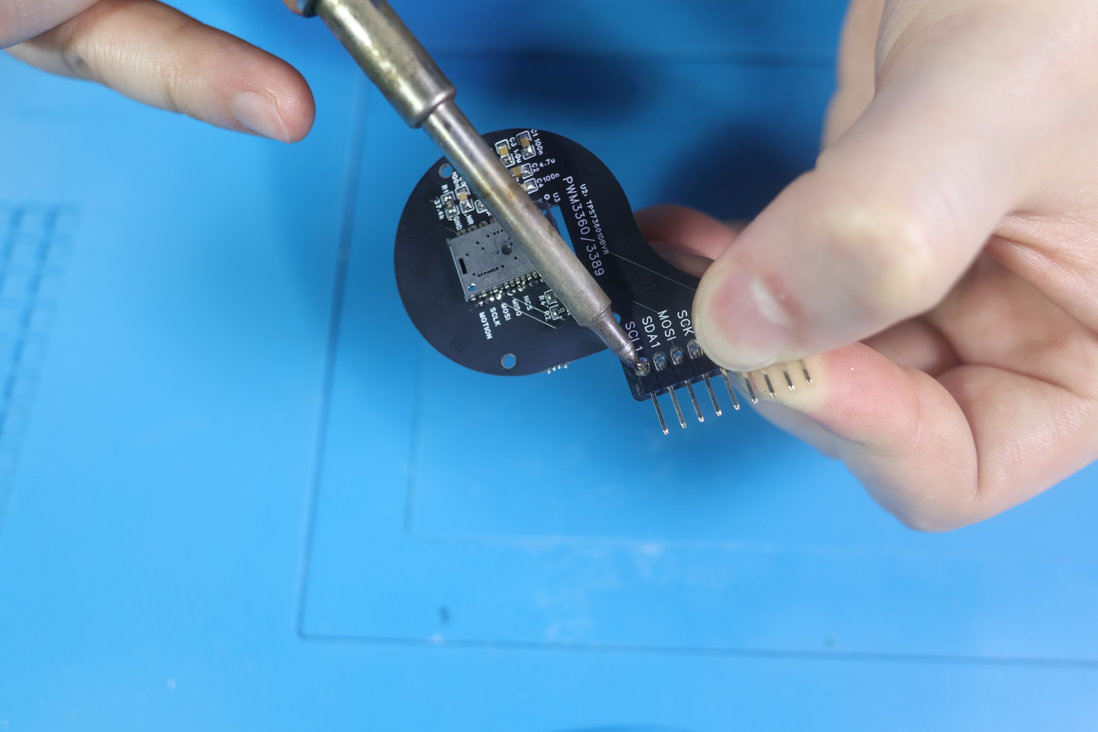
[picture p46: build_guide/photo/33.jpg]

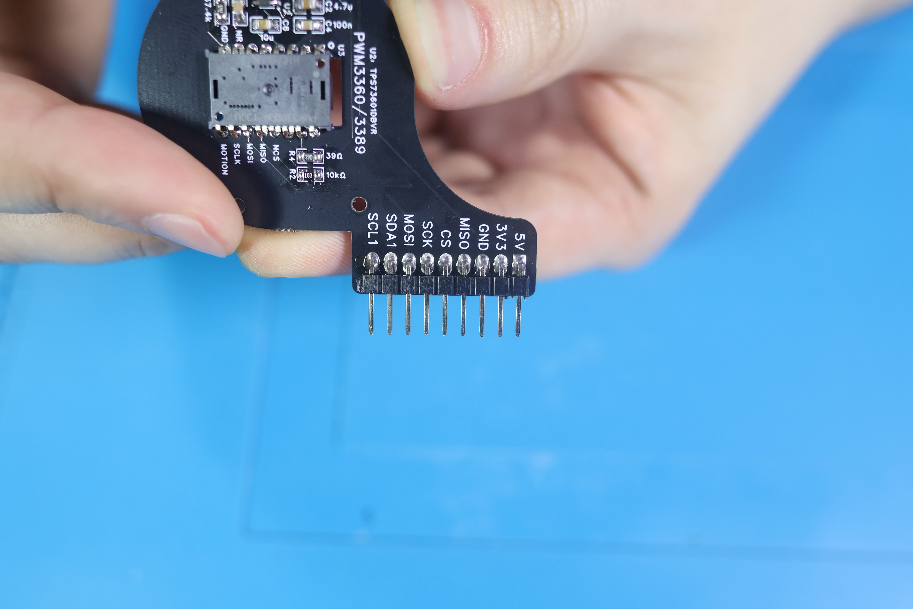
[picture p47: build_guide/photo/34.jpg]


Trim the pins on the reverse side.
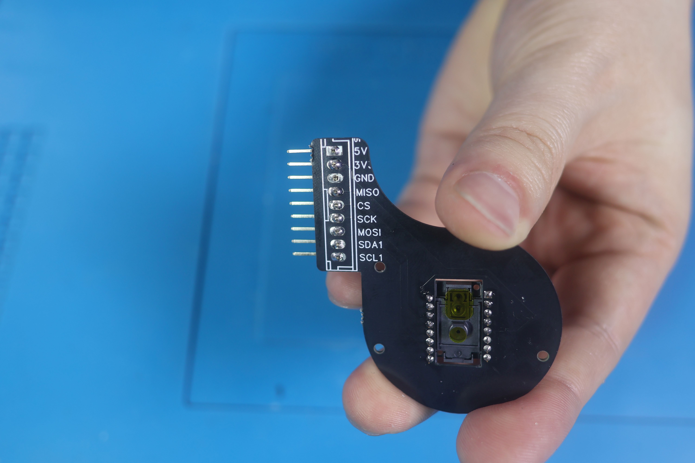
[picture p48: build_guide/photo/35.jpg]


#### Installation of the lens

Peel off both protective films.
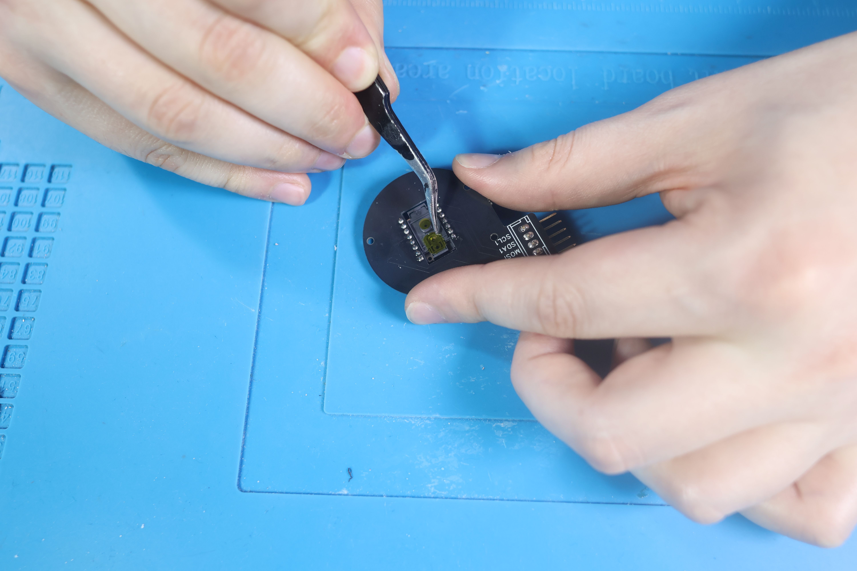
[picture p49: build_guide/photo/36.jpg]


Place the lens onto the sensor alignment posts. Carefully melt the two plastic posts using the soldering iron tip to secure the lens to the sensor assembly.
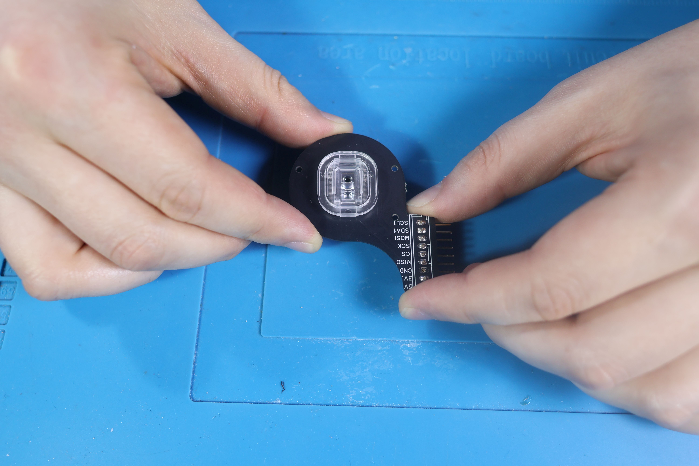
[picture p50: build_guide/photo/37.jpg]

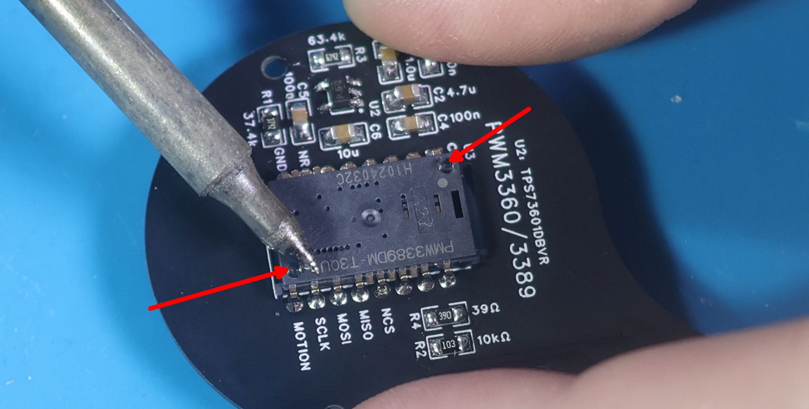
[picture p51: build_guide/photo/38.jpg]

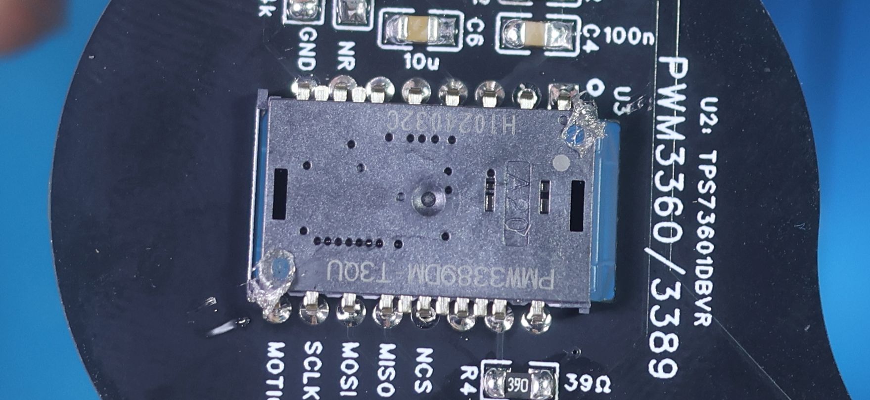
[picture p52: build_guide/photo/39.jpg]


### Preparing the encoder module PCB

#### Installation of 1N4148W diodes (SOD-123)

Solder the diodes, remembering the polarity ("line to line").
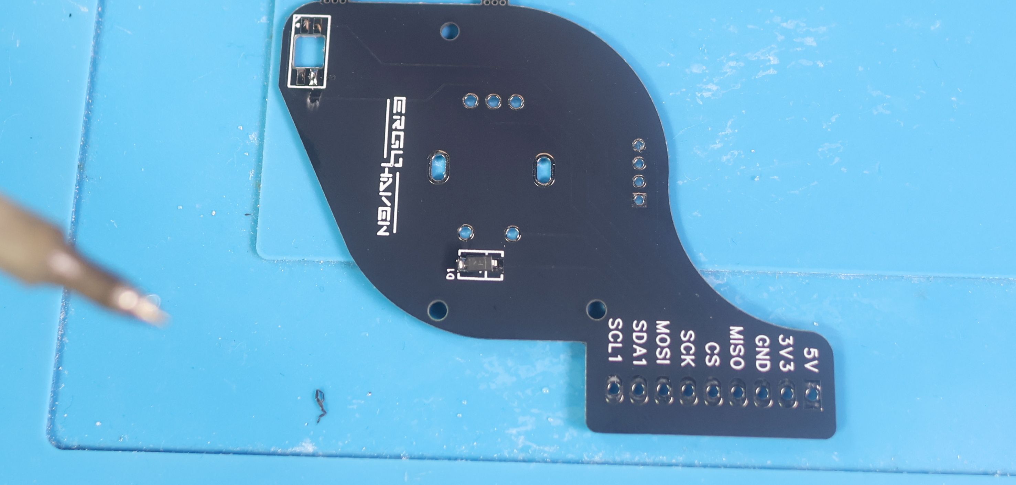
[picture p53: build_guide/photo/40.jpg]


#### Installation of sk6812 mini-e LEDs

Apply solder to one pad for each LED location. The LED has one clipped/notched corner; align this corner with the key (white dot or similar mark) on the PCB silkscreen.


#### Installation of PLS pin connectors

Solder one end pin first to fix the position. Then solder the remaining pins. Trim the pins on the reverse side.



#### Installation of the encoder

Insert the encoder into the holes and solder its pins on the reverse side. Also, solder the two large mounting tabs for stability.



### Preparing the touchpad module PCB

#### Installation of PLS pin connectors

Solder one end pin first to fix the position. Then solder the remaining pins. Trim the pins on the reverse side.



#### Installation of the PH2.0 4 pins, 2mm connector

Place the connector according to the silkscreen outline on the PCB and solder its pins.




### Main body assembly

#### Installation of switches 

First, install switches into the case as shown in the picture. These will help align the PCBs.


#### Installation of the thumb cluster PCB

Place the thumb cluster PCB onto the switches and secure it with M2x4 screws.


#### Installation of the switchplate

Align the Switchplate over the installed switches. While pressing it firmly against the case, fasten one M2x4 screw near the thumb cluster area as shown.



Then, fasten the remaining M2x4 screws. The result should look like the picture.


#### Installation of magnets into the case

**Very important!** Ensure you maintain consistent polarity for the magnets. All magnets on the main case halves should have the *same pole* facing outwards. Magnets on the modules will need the *opposite pole* facing outwards to attract. Use one magnet to test the polarity of others before inserting.

Press the magnets into the designated holes using pliers, as shown.



#### Installation of brass inserts

Using a heated soldering iron, carefully press five M3x4 brass inserts into the holes around the perimeter of the case half, as shown. Apply gentle, steady pressure until the insert is flush with the plastic surface.



#### Installation of the MCU holder

Take the male PLS 11-Pin connector and insert it into the female PBS 11-Pin socket on the prepared MCU holder, as shown.


Position the MCU holder in the case and fasten the M3x4 screw as shown.


Next, while pressing the MCU holder down firmly, solder each pin of the male PLS connector to the corresponding pads on the Switchplate PCB.



#### Connecting the cable-connectors

Connect the Thumb cluster PCB to the MCU Holder PCB using the SH1.0 5-pin cable-connector.


#### Installation of remaining switches and keyboard check

After assembling both halves similarly, install all the remaining switches. Connect the two halves using the Type-C to Type-C cable and connect the keyboard to the PC.


Next, you need to check the keyboard:
-   Go to [Vial](https://get.vial.today/download/).
-   Click on the “Matrix tester” menu, then “Test Matrix” (or similar, depending on Vial version). If required, click "Unlock" and follow the on-screen instructions to enable configuration/testing.
-   Press each key and verify it registers correctly in the matrix tester.

If all keys work correctly, proceed to install the bottom plates.

#### Installation of the bottom plate and keycaps

Place the bottom plate onto the case half and fasten it using M3x4 screws. Then, apply the silicone legs.



Install your favorite keycaps!

### Encoder module assembly


#### Installation of LED insert (Galaxy black case)

Press the LED insert (diffuser) into the hole for the LED, as shown.



#### Installation of magnets

Press the magnets into the holes. Remember: these magnets must have the opposite polarity facing outwards compared to the magnets on the main case.


#### Installation of the PCB

Place the prepared Encoder Module PCB into the module case and fasten it with two M2x4 screws.


#### Installation of the cover, knob, and bumpons

Snap the bottom cover into place. Apply the bumpons/silicone legs. Press the encoder knob onto the encoder shaft.




### Trackball module assembly


#### Installation of bearing balls

Using tweezers, carefully place one 3mm bearing ball into each of the three sockets. Then, use the main 38mm trackball to gently press each bearing ball fully into its socket, one at a time.




#### Installation of magnets

Press the magnets into the holes. Ensure opposite polarity to the main body magnets.


#### Installation of the PCB

Place the prepared Trackball Module PCB into the module case and secure it with two M2x4 screws.


#### Installation of the cover and bumpons

Snap the bottom cover into place. Apply the bumpons/silicone legs. Place the 38mm main ball onto the bearing balls.




### Touchpad Module Assembly


#### Installation of the cable-connector

Solder the PH2.0 cable-connector wires to the Azoteq TPS43 touchpad PCB as shown. Optionally, apply hot glue over the solder points.



#### Installation of the touchpad surface

Peel off the protective films from the touchpad surface piece and the Azoteq touchpad itself. Carefully adhere the surface piece to the touchpad (the glue will already be applied to the touchpad).





#### Installation of the touchpad into the case

Place the assembled touchpad into the module case as shown. Route the cable carefully.




#### Installation of the PCB

Connect the PH2.0 cable from the touchpad to the connector on the prepared Touchpad Module PCB. Place the PCB into the case and secure it with M2x4 screws.




#### Installation of magnets

Press the magnets into the holes. Ensure opposite polarity to the main body magnets.


#### Installation of the cover and bumpons

Snap the bottom cover into place and apply the bumpons/silicone legs.



Your HPDv2 is ready! Enjoy the comfort and ergonomics!


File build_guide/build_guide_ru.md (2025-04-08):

# HPD v2 - как его собрать самостоятельно

## Компоненты:  

### Основной корпус клавиатуры 

- 1 шт. Свитчплейт плата (FR4, 0.8мм толщина)
- 1 шт. Плата для клавиш тамбкластера (FR4, 0.8мм толщина)
- 1 шт. Плата холдера контроллера (FR4, 1мм толщина)
- 1 шт. 3D корпус (правая и левая половинки)
- 2 шт. RP2040 Zero микроконтроллер [(пример)](https://aliexpress.ru/item/1005008447219836.html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)
- 60 шт. MX Хотсвап Сокеты [(пример)](https://aliexpress.ru/item/32965920593.html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)
- 60 шт. 1N4148W Диоды (SOD-123) [(пример)](https://aliexpress.ru/item/1005008585308341.html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)
- 2 шт. PLS пин-коннекторы угловые, папа : 11 пинов, 2.54мм, угловые [(пример)](https://aliexpress.ru/item/1005003912826649.html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)
- 2 шт. PBS сокеты для коннекторов, мама: 11 пинов, 2.54мм, угловые [(пример)](https://aliexpress.ru/item/1005007724558861.html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)
- 2 шт. PBS сокеты для коннекторов, мама: 9 пинов, 2.54мм, угловые [(пример)](https://aliexpress.ru/item/1005007724558861.html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)
- 4 шт. SH1.0 5 Pins, 1.00mm разъёмы [(пример)](https://aliexpress.ru/item/1005005552109946.html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)
- 2 шт  SH1.0 5 Pins, 1mm, 100mm, double head кабель-коннектор [(пример)](https://aliexpress.ru/item/4000820462275.html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)
- 2 шт. 1-100kOhm резисторы (0805) [(пример)](https://aliexpress.ru/item/1005004542018347.html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)
- 4 шт. Магниты n52 5х10х2 мм [(пример)](https://aliexpress.ru/item/1005001564760861.html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)
- 2 шт. USB Type-C мини-плата: 1.6мм толщина [(пример)](https://aliexpress.ru/item/1005005857575118.html)
- 32 шт. M2x4 Винт [(пример)](https://aliexpress.ru/item/1005005898007060.html)
- 10 шт. M3x4 Латунные вставки [(пример)](https://aliexpress.ru/item/1005004290019650.html) 
- 10 шт. M3x4 Винт [(пример)](https://aliexpress.ru/item/1005005898007060.html) 
- 1 шт. Type-C к Type-C кабель (для соединения половинок)
- 8 шт. 3M бампоны/Силиконовые ножки [(пример)](https://aliexpress.ru/item/32912066603.html)
- 60 шт. Свитчи МХ 
- 60 шт. Кейкапы 

### Модули

#### Энкодер

- 1 шт. плата (FR4, 1мм толщина) 
- 1 шт. 3D корпус
- 1 шт. Энкодер EC11 [(пример)](https://aliexpress.ru/item/1005006781489585.html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)
- 1 шт. PLS пин-коннекторы угловые, папа : 9 пинов, 2.54мм, угловые [(пример)](https://aliexpress.ru/item/1005003912826649.html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)
- 1 шт. 1N4148W Diodes (SOD-123) [(пример)](https://aliexpress.ru/item/1005008585308341.html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)
- 1 шт. LED sk6812 mini-e [(пример)](https://aliexpress.ru/item/1005005237439694.html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)
- 2 шт. Магниты n52 5х10х2 мм [(пример)](https://aliexpress.ru/item/1005001564760861.html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)
- 2 шт. 3M бампоны/Силиконовые ножки [(пример)](https://aliexpress.ru/item/32912066603.html)
- 1 шт. Колпачок для энкодера ЕС11 диаметр 26мм высота 17мм
- 2 шт. Вставка для светодиодов (для Galaxy black)

#### Тачпад

- 1 шт. Плата (FR4, 1мм толщина) 
- 1 шт. 3D корпус
- 1 шт. Azoteq TPS43 
- 1 шт. PLS пин-коннекторы угловые, папа : 9 пинов, 2.54мм, угловые [(пример)](https://aliexpress.ru/item/1005003912826649.html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)
- 1 шт. PH2.0 4 pins, 2mm, 90 degree разъём [(пример)](https://aliexpress.ru/item/1005008351868561.html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)
- 1 шт. PH2.0 4 Pins, 2mm, 6mm, one head кабель-коннектор [(пример)](https://aliexpress.ru/item/32936172012.html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)
- 2 шт. Магниты n52 5х10х2 мм [(пример)](https://aliexpress.ru/item/1005001564760861.html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)
- 2 шт. 3M бампоны/Силиконовые ножки [(пример)](https://aliexpress.ru/item/32912066603.html)
- 1 шт. Покрытие для тачпада 40х43х1 мм с закруглениями 3мм 
- 1 шт. Плёнка на тачпад ПВХ 40х43 мм с закруглениями 3мм

#### Трекбол

- 1 шт. Плата (FR4, 1мм толщина) 
- 1 шт. 3D корпус
- 1 шт. PWM3389DM сенсор + линза 
- 1 шт. TPS73601DBVR [(пример)](https://aliexpress.ru/item/1005008567384914.html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)
- 1 шт. PLS пин-коннекторы угловые, папа : 9 пинов, 2.54мм, угловые [(пример)](https://aliexpress.ru/item/1005003912826649.html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)
- 1 шт. Резистор 0805 10 kOm [(пример)](https://aliexpress.ru/item/1005004542018347.html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)
- 1 шт. Резистор 0805 39 Om [(пример)](https://aliexpress.ru/item/1005004542018347.html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)
- 1 шт. Резистор 0805 37.4 kOm [(пример)](https://aliexpress.ru/item/1005008488375993.html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)
- 1 шт. Резистор 0805 63.4 kOm [(пример)](https://aliexpress.ru/item/1005007715575103.html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)
- 3 шт. Конденсатор 0805 100 nF [(пример)](https://aliexpress.ru/item/1005007108081207.html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)
- 1 шт. Конденсатор 0805 1 uF [(пример)](https://aliexpress.ru/item/1005007108081207.html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)
- 1 шт. Конденсатор 0805 4.7 uF [(пример)](https://aliexpress.ru/item/1005007108081207.html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)
- 1 шт. Конденсатор 0805 10 uF [(пример)](https://aliexpress.ru/item/1005007108081207.html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)
- 2 шт. Магниты n52 5х10х2 мм [(пример)](https://aliexpress.ru/item/1005001564760861.html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)
- 2 шт. 3M бампоны/Силиконовые ножки [(пример)](https://aliexpress.ru/item/32912066603.html)
- 1 шт. Шар 38 мм 
- 3 шт. Шарики для подшипников стальные/керамические диаметр 3мм [(пример)](https://aliexpress.ru/item/1005006326053912.html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)

## Инструменты: 

- Паяльник
- Припой (флюсосодержащий)
- Кусачки
- Пинцет
- Отвёртка для винтов M3 и M2
- Плоскогубцы

## Порядок сборки

### Подготовка холдера 

1. Установка резисторов
2. Установка микроконтроллера
3. Установка Type-C коннекторов
4. Установка SH1.0 5 Pins, 1.00mm разъёмов
5. Установка PBS 11-R и 9-R коннекторов
6. Прошивка микроконтроллера

### Подготовка свитчплейта 

1. Нанесение припоя на контактные площадки
2. Установка хотсвап сокетов и диодов

### Подготовка платы для тамбкластера

1. Установка SH1.0 5 Pins, 1.00mm разъёмов 
2. Нанесение припоя и установка хотсвап сокетов и диодов

### Подготовка платы для модуля трекбола

1. Установка микросхемы TPS73601DBVR
2. Нанесение припоя на контактные площадки
3. Установка резисторов и конденсаторов
4. Установка PWM3389DM сенсора
5. Установка PLS пин-коннекторов
6. Установка линзы

### Подготовка платы для модуля энкодера

1. Установка диодов 1N4148W (SOD-123)
2. Установка светодиодов sk6812 mini-e
3. Установка PLS пин-коннекторов
4. Установка энкодера

### Подготовка платы для модуля тачпада

1. Установка PLS пин-коннекторов
2. Установка PH2.0 4 pins, 2mm разъёма

### Сборка основного корпуса

1. Установка переключателей
2. Установка платы для тамбкластера
3. Установка свитчплейта
4. Установка магнитов в корпус
5. Установка латунных вставок
6. Установка холдера
7. Подключение кабель-коннекторов
8. Установка свитчей и проверка клавиатуры
9. Установка нижнего плейта и кейкапов

### Сборка модуля энкодера

1. Установка вставки для светодиодов (Galaxy black)
2. Установка магнитов
3. Установка платы
4. Установка крышки, колпачка и бомпонов

### Сборка модуля трекбола

1. Установка шариков для подшипников
2. Установка магнитов
3. Установка платы
4. Установка крышки и бомпонов

### Сборка модуля тачпада

1. Установка кабель-коннектора 
2. Установка покрытия для тачпада
3. Установка тачпада в корпус
4. Установка платы
5. Установка магнитов
6. Установка крышки и бомпонов

### Подготовка холдера 

#### Установка резисторов

Для начала необходимо подготовить плату для холдера. Устанавливаем резисторы на обе половинки холдера. На правой половинке — на площадку R3, на левой — на R2.


#### Установка микроконтроллера

Не перепутайте сторону установки. Ставим ровно микроконтроллер и сначала запаиваем 0 и 13 пины, чтобы его зафиксировать на плате. После того, как мы ровно зафиксировали микроконтроллер - запаиваем остальные контакты. 



#### Установка Type-C коннекторов

Размещаем Type-C коннектор на холдере и запаиваем один контакт, чтобы зафиксировать PLS коннектор, как показано на рис. 1.
Затем с другой стороны запаиваем также один контакт PLS коннектора, как показано на рис. 2. Далее допаиваем все контакты с лицевой стороны платы, как показано на рис. 3.
После обрезаем лишние ножки кусачками и допаиваем Type-C коннектор.






#### Установка SH1.0 5 Pins, 1.00mm разъёмов

Запаиваем контактную площадку для фиксации разъёма 


Устанавливаем разъём и запаиваем остальные контакты.




#### Установка PBS 11-R и 9-R коннекторов

Запаиваем PBS 11-R коннектор по одному крайнему контакту для фиксации. Далее запаиваем остальные контакты.




Затем запаиваем PBS 9-R коннекторы, размещая их как на рисунке.



После, с обратной стороны обрезаем пины кусачками.



#### Прошивка микроконтроллера

После того, как мы закончили с пайкой холдеров, необходимо их прошить: 
- Подключаем микроконтроллер к ПК
- Микроконтроллер должен определиться как USB накопитель  
- Перетаскиваем на него [файл прошивки](https://github.com/ergohaven/keymap_hub/)  
- Микроконтроллер прошит  

Если у вас RP2040-Zero не определился как накопитель, то необходимо 
зажать на нём клавишу Boot и подключить USB. Затем повторить действия с перетаскиванием Uf2 файла прошивки.

### Подготовка свитчплейта

#### Нанесение припоя на контактные площадки 

Для начала необходимо подготовить плату. Для этого наносим припой на контактные площадки с одной стороны компонентов, чтобы их было легче припаивать.


#### Установка хотсвап сокетов и диодов

Диоды имеют полярность и поэтому важно устанавливать их правильной стороной. Катод отмечен белой линией на диоде. На платах также имеется шелкография с такой же линией. Паяем «линия к линии».
Все диоды должны быть установлены в одном направлении.

Далее необходимо установить хотсвап сокеты и запаять их.


### Подготовка платы для тамбкластера

#### Установка SH1.0 5 Pins, 1.00mm разъёмов 

Запаиваем разъём аналогично, как на холдере. Обратите внимание, чтобы боковые контакты были надёжно запаяны.




#### Нанесение припоя и установка компонентов

Запаиваем также, как на свитчплейте.


### Подготовка платы для модуля трекбола

#### Установка микросхемы TPS73601DBVR

Нанесение припоя на среднюю контактную площадку для фиксации микросхемы.


Далее устанавливаем и запаиваем микросхему.



#### Нанесение припоя на контактные площадки

Наносим припой на контактные площадки с одной стороны компонентов, чтобы их было легче припаивать.


#### Установка резисторов и конденсаторов

Запаиваем все резисторы и конденсаторы в соответствии с шелкографией. У данных компонентов нет полярности. 


#### Установка PWM3389DM сенсора

Установить сенсор, "меткой к метке" как на рисунке и запаиваем его.



#### Установка PLS пин-коннекторов

Запаиваем по одному крайнему контакту для фиксации. Далее запаиваем остальные контакты. 



Обрезаем пины с обратной стороны.


#### Установка линзы

Отклеиваем обе защитные плёнки.


Устанавливаем линзу и аккуратно паяльником расплавляем 2 крепления, для фиксации линзы к сенсору.




### Подготовка платы для модуля энкодера

#### Установка диодов 1N4148W (SOD-123)

Запаиваем диоды, не забывая про полярность.


#### Установка светодиодов sk6812 mini-e

Наносим припой на контактные площадки с одной стороны. Светодиод имеет 1 подрезанную ножку её надо расположить к ключу (белой точке) на плате.


#### Установка PLS пин-коннекторов

Запаиваем по одному крайнему контакту для фиксации. Далее запаиваем остальные контакты. Затем обрезаем пины с обратной стороны.



#### Установка энкодера

Устанавливаем энкодер в отверстие и запаиваем контакты с обратной стороны. 



### Подготовка платы для модуля тачпада

#### Установка PLS пин-коннекторов

Запаиваем по одному крайнему контакту для фиксации. Далее запаиваем остальные контакты. Затем обрезаем пины с обратной стороны.



#### Установка PH2.0 4 pins, 2mm разъёма

Устанавливаем разъём в соответствии с шелкографией на плате и запаиваем. 




### Сборка основного корпуса

#### Установка переключателей

Для начала необходимо установить свитчи в корпус, как показано на рисунке.


#### Установка платы для тамбкластера

Устанавливаем плату на свитчи и закручиваем винтами.


#### Устанавливаем свитчплейт 

Закрепляем его на свитчи и прижимая к корпусу, закручиваем винт М2х4, как показано на рисунке.



Затем закручиваем остальные винты, результат должен выглядеть как на рисунке.


#### Установка магнитов в корпус

Очень важно! Обязательно соблюдайте полярность магнитов, чтобы магниты на корпусе были установлены одинаковой полярностью и могли притягиваться к магнитам на модулях. На модулях магниты устанавливаются противоположной полярностью.

Вдавливаем магниты плоскогубцами в отверстия, как на рисунках.



#### Установка латунных вставок

Устанавливаем пять латунных вставок на половинку разогретым паяльником по периметру корпуса, как показано на рисунке ниже.



#### Установка холдера 

Берём PLS 11-R и вставляем в коннектор на холдере, как показано на рисунке.


Устанавливаем холдер и закручиваем М3х4 винт, как показано на рисунке.


Далее, придавливая холдер до упора, запаиваем каждый пин PLS разъёма на свитчплейт. 



#### Подключение кабель-коннекторов

Соединяем тамбкластер с холдером, используя кабель-коннектор.


#### Установка свитчей и проверка клавиатуры

После того, как мы собрали обе половинки, устанавливаем все свитчи, соединяем их между собой Type-C кабелем и подключаем клавиатуру к ПК.


Далее, нам необходимо будет проверить клавиатуру:  
- Заходим в [Vial](https://get.vial.today/download/)  
- Кликаем на меню “Matrix tester”, дальше “Unlock” и следуем инструкции на экране для разблокировки клавиатуры  
- Проверяем каждую клавишу

Если все клавиши работают корректно, то начинаем закручивать нижние плейты.

#### Установка нижнего плейта и кейкапов

Помещаем плейт в корпус и закручиваем его М3х4 винтами, затем устанавливаем силиконовые ножки, как на рисунке.



Установите Ваши любимые кейкапы!

### Сборка модуля энкодера


#### Установка вставки для светодиодов (Galaxy black)

Вдавливаем вставку в отверстие для светодиода, как на рисунках.



#### Установка магнитов

Вдавливаем магниты в отверстия.
На модулях магниты устанавливаются противоположной полярностью по отношению к магнитам на корпусе.


#### Установка платы

Устанавливаем плату и закручиваем двумя винтами.


#### Установка крышки, колпачка и бомпонов

Защёлкиваем крышку, устанавливаем бампоны и колпачок для энкодера.




### Сборка модуля трекбола


####  Установка шариков для подшипников

Устанавливаем пинцетом по одному 3 мм шарику в отверстие и вдавливаем их основным шаром, как на рисунке. Каждый шарик вдавливается по отдельности.





####  Установка магнитов

Вдавливаем магниты в отверстия.
На модулях магниты устанавливаются противоположной полярностью по отношению к магнитам на корпусе.


####  Установка платы

Устанавливаем плату и закручиваем двумя винтами.


####  Установка крышки и бомпонов

Защёлкиваем крышку, устанавливаем бампоны и основной шар 38 мм.




### Сборка модуля тачпада


#### Установка кабель-коннектора 

Припаиваем кабель-коннектор, как на рисунке. Опционально можно нанести горячий клей на контакты для надёжности.



#### Установка покрытия для тачпада

Отклеиваем защитные плёнки с покрытия для тачпада и с самого тачпада. Затем покрытие приклеиваем к тачпаду (клей на тачпад нанесён с завода).






#### Установка тачпада в корпус

Устанавливаем тачпад в корпус, как показано на рисунках.




#### Установка платы

Соединяем плату с разъёмом и прикручиваем её винтами к корпусу.




#### Установка магнитов

Вдавливаем магниты в отверстия.
На модулях магниты устанавливаются противоположной полярностью по отношению к магнитам на корпусе.


#### Установка крышки и бомпонов

Защёлкиваем крышку и устанавливаем бампоны.



Ваша HPDv2 готова! Наслаждайтесь комфортом и эргономикой!
